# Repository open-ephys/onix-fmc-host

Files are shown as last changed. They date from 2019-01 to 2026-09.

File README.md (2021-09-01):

# ONIX FMC Host
This card provides a host interface for serialized headstages and miniscopes, as
well as general purpose analog and digital IO. It is a VITA-57.1
compliant module that uses high pin-count FMC connector. In combination with a
base FPGA board (e.g. [Numato Lab
Nereid](https://numato.com/product/nereid-kintex-7-pci-express-fpga-development-board),
it provides host PC communication for the following:

- Two deserailizers for any multifunction headstage conforming to the ONIX
  serialization protocol
- 12x 16-bit, +/-10V analog outputs or inputs. Direction selected via analog
  switch controllable over the FMC connector. Analog inputs are separated into
  2 simultaneously sampled 6-channel banks. 
- Analog output are always looped back using the analog inputs.
- 3x high speed LVDS input pairs
- 2x high speed LVDS outputs pairs
- 2x high speed, arbitrary logic-level, singled-ended Hi-Z or 50-ohm clock inputs
- 1x high speed single ended, 50-ohm clock output
- 4x MLVDS input or output trigger lines

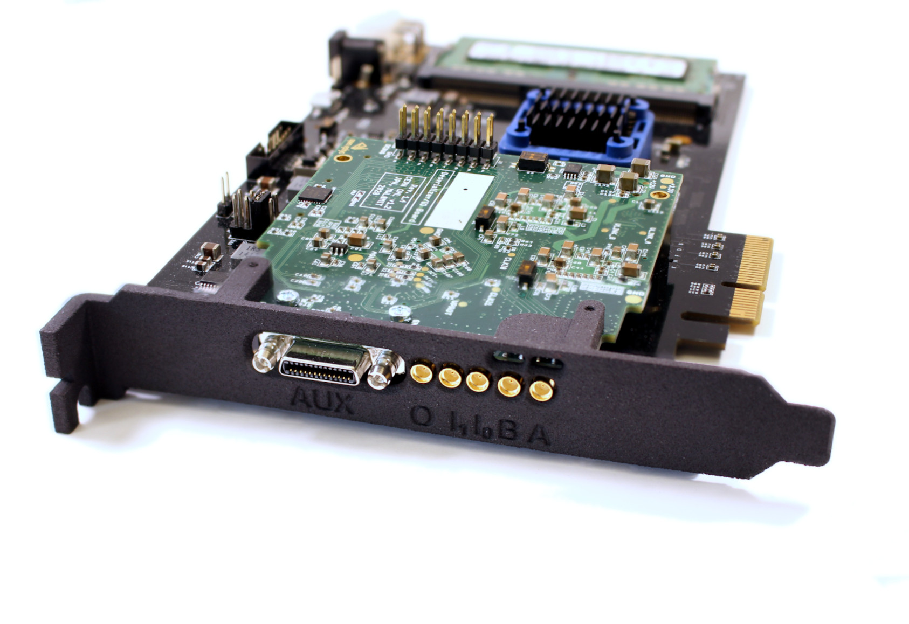
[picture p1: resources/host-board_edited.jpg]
fmc-host revision 1.4 on Numato Lab Nereid


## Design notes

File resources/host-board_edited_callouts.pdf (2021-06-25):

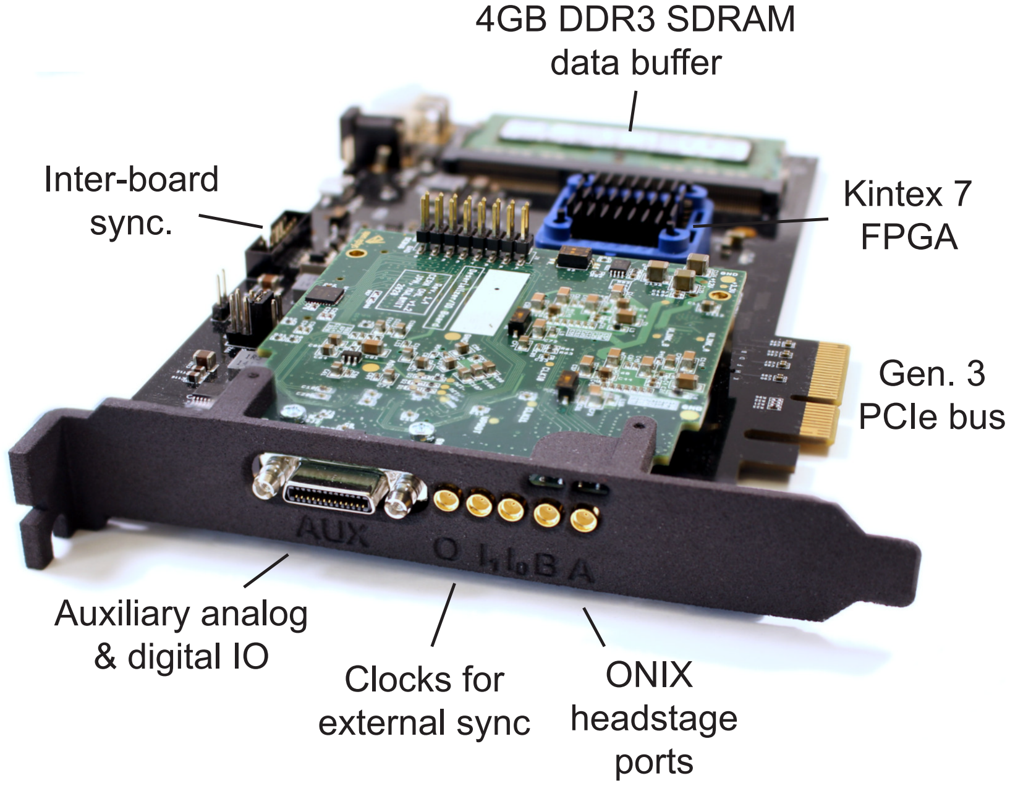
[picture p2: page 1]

Auxiliary analog
& digital IO | Clocks for
| external sync

ONIX
headstage
ports

Gen. 3
PCIe bus

4GB DDR3 SDRAM
data buffer

Kintex 7
FPGA

Inter-board
sync.

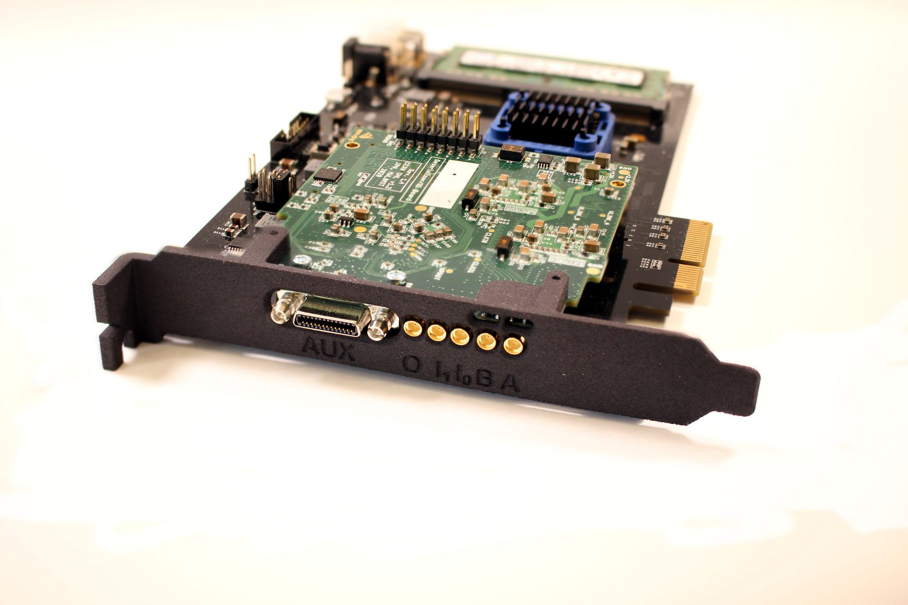
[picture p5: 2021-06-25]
resources/host-board-focus-stack.png

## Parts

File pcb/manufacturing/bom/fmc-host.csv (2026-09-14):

# | Qty | Reference | Value | Tolerance | Footprint | TempCo | Voltage | DNP | OEPS PN | MPN | LCSC | OEPS Description
1 | 23 | C1,C2,C5,C6,C26,C27,C34,C35,C36,C37,C70,C71,C72,C73,C79,C80,C81,C91,C92,C106,C118,C139,C140 | 10uF |  | fmc-host:1206 |  |  |  | OEPS010007 | GRM31CR71E106KA12L |  | CAPACITOR: SMD CER 1206 10uF 25V ±10% X7R [GRM31CR71E106KA12L] [SMD]
2 | 62 | C3,C4,C7,C8,C9,C10,C13,C14,C15,C16,C17,C18,C19,C22,C23,C30,C31,C32,C33,C41,C43,C44,C45,C46,C47,C48,C49,C52,C53,C54,C55,C56,C60,C61,C63,C65,C67,C68,C78,C83,C84,C85,C86,C87,C89,C90,C93,C99,C100,C104,C107,C110,C111,C112,C114,C132,C134,C135,C137,C138,C141,C142 | 0.1uF |  | fmc-host:0402 | X7R | 25V |  | OEPS010004 | GRM155R71E104KE14D |  | CAPACITOR: SMD CER 0402 100nF 25V ±10% X7R [GRM155R71E104KE14D] [SMD]
3 | 14 | C11,C12,C20,C21,C24,C25,C50,C51,C57,C58,C82,C122,C123,C124 | 10nF |  | fmc-host:0402 |  |  |  | OEPS010002 | GCM155R71E103KA37D |  | CAPACITOR: SMD CER 0402 10nF 25V ±10% X7R [GCM155R71E103KA37D] [SMD]
4 | 2 | C28,C29 | 4.7nF |  | fmc-host:0402 |  |  |  | OEPS010001 | CC0402KRX7R8BB472 |  | CAPACITOR: SMD CER 0402 4.7nF 25V ±10% X7R [CC0402KRX7R8BB472] [SMD]
5 | 2 | C38,C39 | 47nF |  | fmc-host:0402 |  |  |  | OEPS010003 | GRM155R71E473KA88D |  | CAPACITOR: SMD CER 0402 47nF 25V ±10% X7R [GRM155R71E473KA88D] [SMD]
6 | 8 | C40,C42,C64,C66,C74,C75,C76,C88 | 1uF |  | fmc-host:0805 |  |  |  | OEPS010005 | GCM21BR71E105KA56L |  | CAPACITOR: SMD CER 0805 1uF 25V ±10% X7R [GCM21BR71E105KA56L] [SMD]
7 | 20 | C59,C62,C69,C77,C95,C96,C101,C103,C105,C108,C109,C113,C116,C117,C119,C120,C121,C125,C126,C127 | 10uF |  | fmc-host:0805 |  |  |  | OEPS010006 | GRM21BR61E106KA73L |  | CAPACITOR: SMD CER 0805 10uF 25V ±10% X5R [GRM21BR61E106KA73L] [SMD]
8 | 6 | C94,C97,C98,C102,C130,C131 | 47uF |  | fmc-host:1210 |  |  |  | OEPS010008 | TMK325ABJ476MM-T |  | CAPACITOR: SMD CER 1210 47uF 25V ±20% X5R [TMK325ABJ476MM-T] [SMD]
9 | 1 | C115 | 100pF |  | fmc-host:0402 |  |  |  | OEPS010089 | CC0402JRNPO9BN101 |  | CAPACITOR: SMD CER 0402 100pF 50V ±5% C0G [CC0402JRNPO9BN101] [SMD]
10 | 2 | C128,C129 | 0.1uF, 500V |  | fmc-host:1210 |  |  |  | OEPS010091 | C1210C104KCRACTU |  | CAPACITOR: SMD CER 1210 100nF 500V ±10% X7R [C1210C104KCRACTU] [SMD]
11 | 2 | C133,C136 | 33uF |  | fmc-host:1411-VISHAY-B |  |  |  | OEPS210010 | TL8B0336M020C |  | CAPACITOR POL: SMD TANT B0 1411 33uF 20V ±20% 50Ohm [TL8B0336M020C] [SMD]
12 | 2 | D1,D2 | SESD0402X1UN-0030-088 |  | fmc-host:0402P-DFN |  |  |  | OEPS030049 | SESD0402X1UN-0030-088 |  | DIODE: TVS DIODE 7VWM 13VC [SESD0402X1UN-0030-088] [0402/2DFN]
13 | 3 | D3,D4,D5 | BAR66 |  | fmc-host:SOT23 |  |  |  | OEPS030050 | BAR66E6327HTSA1 |  | DIODE: RF DIODE PIN 150V 250MW [BAR66E6327HTSA1] [PG-SOT23]
14 | 1 | D6 | KDZVTR4.3B |  | fmc-host:SOD123 |  |  |  | OEPS030051 | KDZVTR4.3B |  | DIODE: DIODE ZENER 4.55V 1W [KDZVTR4.3B] [PMDU]
15 | 3 | F1,F2,F3 | C014F-2 |  | fmc-host:1812 |  |  |  | OEPS100088 | MINISMDC014F-2 |  | OTHER: PTC RESET FUSE 60V 140MA 1812 [MINISMDC014F-2] [Other]
16 | 5 | J1,J2,J3,J4,J5 | 6-1634010-0 |  | fmc-host:MMCX-THRU |  |  |  | OEPS070081 | 262105 |  | CONNECTOR: MMCX RCPT 50ohm 90º [262105] [TH]
17 | 1 | J6 | FTSH-105-01-F-D-RA-K |  | fmc-host:FTSH-105-01-F-D-RA-K |  |  |  | OEPS070147 | FTSH-105-01-F-D-RA-K |  | CONNECTOR: HEADER 1.27MM R/A 10POS [FTSH-105-01-F-D-RA-K] [TH]
18 | 1 | J7 | 12226-8250-00FR |  | fmc-host:12226-82X0-00XX |  |  |  | OEPS070009 | 12226-8250-00FR |  | CONNECTOR: SDR RCPT 90º 26POS [12226-8250-00FR] [SMD]
19 | 1 | J9 | ASP-134488-01 |  | fmc-host:FMC_HPC_MALE |  |  |  | OEPS070148 | ASP-134488-01 |  | CONNECTOR: ARRAY PLUG 400POS GOLD [ASP-134488-01] [SMD]
20 | 1 | J10 | BM08B-SURS-TF |  | fmc-host:BM08B-SURS-TF |  |  |  | OEPS070149 | BM08B-SURS-TF |  | CONNECTOR: HEADER 0.8MM 8POS [BM08B-SURS-TF] [SMD]
21 | 2 | L1,L2 | 1008PS-472 |  | fmc-host:1008PS |  |  |  | OEPS040032 | 1008PS-472KLC |  | INDUCTOR: FIXED INDUCTOR SMD 4.7uH 950mA 350mΩ [1008PS-472KLC] [-]
22 | 6 | L3,L4,L9,L10,L11,L12 | BLM18KG601SN1D |  | fmc-host:0603 |  |  |  | OEPS040029 | BLM18KG601SN1D |  | INDUCTOR: FERRITE BEAD SMD 0603 600Ω 1.3A 150mΩ (OEPS J30 030) [BLM18KG601SN1D] [0603]
23 | 2 | L5,L6 | SRN6045TA-101M |  | fmc-host:SRN6045TA |  |  |  | OEPS040033 | SRN6045TA-101M |  | INDUCTOR: FIXED INDUCTOR SMD 100uH 920mA 456mΩ [SRN6045TA-101M] [SMD]
24 | 2 | L7,L8 | MPZ2012S102AT000 |  | fmc-host:0805 |  |  |  | OEPS040034 | MPZ2012S102AT000 |  | INDUCTOR: FERRITE BEAD SMD 0805 1kΩ 1.5A 150mΩ [MPZ2012S102AT000] [SMD]
25 | 1 | L13 | 1277AS-H-6R8M=P2 |  | fmc-host:1210 |  |  |  | OEPS040035 | 1277AS-H-6R8M=P2 |  | INDUCTOR: FIXED INDUCTOR SMD 6.8uH 1.2A 276mΩ [1277AS-H-6R8M=P2] [SMD]
26 | 6 | L14,L15,L16,L17,L18,L19 | BLM15PX601SN1D |  | fmc-host:0402 |  |  |  | OEPS040019 | BLM15PX601SN1D |  | INDUCTOR: FERRITE BEAD SMD 0402 600Ω 900mA 230mΩ [BLM15PX601SN1D] [0402]
27 | 4 | Q1,Q2,Q3,Q4 | SI1012R |  | fmc-host:SC75 |  |  |  | OEPS060024 | SI1012CR-T1-GE3 |  | TRANSISTOR: MOSFET N-CH 20V 630mA [SI1012CR-T1-GE3] [SC-75A]
28 | 4 | R1,R2,R38,R39 | 3k |  | fmc-host:0402 |  |  |  | OEPS020008 | ERJ-2RKF3001X |  | RESISTOR: SMD 0402 3kΩ ±1% 0.100W [ERJ-2RKF3001X] [SMD]
29 | 6 | R3,R4,R9,R10,R57,R58 | 2k |  | fmc-host:0402 |  |  |  | OEPS020007 | ERJ-2RKF2001X |  | RESISTOR: SMD 0402 2kΩ ±1% 0.100W [ERJ-2RKF2001X] [SMD]
30 | 6 | R5,R6,R7,R8,R11,R12 | 150,0.25W |  | fmc-host:0603 |  |  |  | OEPS020023 | CRGP0603F150R |  | RESISTOR: SMD 0603 150Ω ±1% 0.250W [CRGP0603F150R] [SMD]
31 | 9 | R13,R14,R49,R50,R51,R52,R76,R83,R84 | 165k |  | fmc-host:0402 |  |  |  | OEPS020020 | ERJ-2RKF1653X |  | RESISTOR: SMD 0402 165kΩ ±1% 0.100W [ERJ-2RKF1653X] [SMD]
32 | 13 | R15,R16,R35,R37,R59,R63,R64,R65,R67,R68,R78,R79,R82 | 10k |  | fmc-host:0402 |  |  |  | OEPS020013 | ERJ-2RKF1002X |  | RESISTOR: SMD 0402 10kΩ ±1% 0.100W [ERJ-2RKF1002X] [SMD]
33 | 8 | R17,R18,R41,R42,R44,R45,R46,R47 | 1k |  | fmc-host:0402 |  |  |  | OEPS020006 | ERJ-2RKF1001X |  | RESISTOR: SMD 0402 1kΩ ±1% 0.100W [ERJ-2RKF1001X] [SMD]
34 | 2 | R19,R21 | 5.6k 1% |  | fmc-host:0402 |  |  |  | OEPS020011 | ERJ-2RKF5601X |  | RESISTOR: SMD 0402 5.6kΩ ±1% 0.100W [ERJ-2RKF5601X] [SMD]
35 | 2 | R20,R22 | 21k 1% |  | fmc-host:0402 |  |  |  | OEPS020016 | ERJ-2RKF2102X |  | RESISTOR: SMD 0402 21kΩ ±1% 0.100W [ERJ-2RKF2102X] [SMD]
36 | 4 | R23,R24,R28,R29 | 49.9 |  | fmc-host:0402 |  |  |  | OEPS020002 | RR0510R-49R9-D |  | RESISTOR: SMD 0402 49.9Ω ±0.5% 0.063W [RR0510R-49R9-D] [SMD]
37 | 3 | R25,R26,R27 | 100 |  | fmc-host:0402 |  |  |  | OEPS020004 | ERJ-2RKF1000X |  | RESISTOR: SMD 0402 100Ω ±1% 0.100W [ERJ-2RKF1000X] [SMD]
38 | 9 | R30,R31,R32,R33,R40,R43,R71,R73,R75 | 4.7k |  | fmc-host:0402 |  |  |  | OEPS020010 | ERJ-2RKF4701X |  | RESISTOR: SMD 0402 4.7kΩ ±1% 0.100W [ERJ-2RKF4701X] [SMD]
39 | 2 | R34,R36 | DNP |  | fmc-host:0402 |  |  | DNP | OEPS000000 | DNP |  | DNP: Do Not Populate (DNI)
40 | 2 | R48,R66 | 0 |  | fmc-host:0402 |  |  |  | OEPS020001 | RC0402JR-070RL |  | RESISTOR: SMD 0402 0Ω 1A [RC0402JR-070RL] [SMD]
41 | 4 | R53,R54,R55,R56 | 2.2k |  | fmc-host:RN2X8-1506 |  |  |  | OEPS080206 | EXB-2HV222JV |  | IC: RES ARRAY 8 RES 2.2K OHM 1506 [EXB-2HV222JV] [SMD]
42 | 2 | R60,R61 | 3.48k |  | fmc-host:0402 |  |  |  | OEPS020009 | ERJ-2RKF3481X |  | RESISTOR: SMD 0402 3.48kΩ ±1% 0.100W [ERJ-2RKF3481X] [SMD]
43 | 1 | R62 | 649k |  | fmc-host:0402 |  |  |  | OEPS020022 | ERJ-2RKF6493X |  | RESISTOR: SMD 0402 649kΩ ±1% 0.100W [ERJ-2RKF6493X] [SMD]
44 | 1 | R69 | 2.2k |  | fmc-host:0402 |  |  |  | OEPS020174 | ERJ-2RKF2201X |  | RESISTOR: SMD 0402 2.2kΩ ±1% 0.100W [ERJ-2RKF2201X] [SMD]
45 | 1 | R70 | 15k |  | fmc-host:0402 |  |  |  | OEPS020015 | ERJ-2RKF1502X |  | RESISTOR: SMD 0402 15kΩ ±1% 0.100W [ERJ-2RKF1502X] [SMD]
46 | 2 | R72,R74 | 47k |  | fmc-host:0402 |  |  |  | OEPS020017 | ERJ-2RKF4702X |  | RESISTOR: SMD 0402 47kΩ ±1% 0.100W [ERJ-2RKF4702X] [SMD]
47 | 1 | R77 | 178k |  | fmc-host:0402 |  |  |  | OEPS020021 | ERJ-2RKF1783X |  | RESISTOR: SMD 0402 178kΩ ±1% 0.100W [ERJ-2RKF1783X] [SMD]
48 | 2 | R80,R81 | 73.2k |  | fmc-host:0402 |  |  |  | OEPS020018 | ERJ-2RKF7322X |  | RESISTOR: SMD 0402 73.2kΩ ±1% 0.100W [ERJ-2RKF7322X] [SMD]
49 | 2 | R289,R290 | 4.7,1W |  | Resistor_SMD:R_1206_3216Metric |  |  |  | OEPS020260 | SG73P2BTTD4R7J |  | RESISTOR: SMD 1206 4.7Ω ±5% 1W [SG73P2BTTD4R7J] [SMD]
50 | 2 | S1,S2 | CHS-01TA |  | fmc-host:DIP01-SMD-GULL |  |  | DNP | OEPS100086 | CHS-01TA |  | OTHER: SWITCH SLIDE DIP SPST 0.1A 6V 1 POS [CHS-01TA] [Other]
51 | 1 | S3 | CHS-02TB |  | fmc-host:CHS-02TB |  |  |  | OEPS100087 | CHS-02TB |  | OTHER: SWITCH SLIDE DIP SPST 0.1A 6V 2 POS [CHS-02TB] [Other]
52 | 1 | U1 | SN74LVC2G34DCKR |  | fmc-host:SC70 |  |  |  | OEPS080207 | SN74LVC2G34DCKR |  | IC: BUFFER NON-INVERT 2CH [SN74LVC2G34DCKR] [SC-70-6]
53 | 1 | U2 | SN65LVDS9638DGN |  | fmc-host:MSOP-8-PAD-3X3 |  |  |  | OEPS080007 | SN65LVDS9638DGN |  | IC: LVDS 2channel driver [SN65LVDS9638DGN] [8-MSOP-PowerPad]
54 | 1 | U3 | FIN1032MTCX |  | fmc-host:TSSOP-16 |  |  |  | OEPS080006 | FIN1032MTCX |  | IC: LVDS 4channel receiver [FIN1032MTCX] [16-TSSOP]
55 | 2 | U4,U5 | ADCMP600 |  | fmc-host:SOT-23-5 |  |  |  | OEPS080208 | ADCMP600BRJZ-R2 |  | IC: COMPARATOR 1 GP [ADCMP600BRJZ-R2] [SOT23-5]
56 | 3 | U6,U7,U8 | DG1412E |  | fmc-host:QFN16-4X4MM |  |  |  | OEPS080209 | DG1412EEN-T1-GE4 |  | IC: SWITCH SPST-NOX4 1.5OHM [DG1412EEN-T1-GE4] [16-QFN (4x4)]
57 | 2 | U9,U10 | DS90UB934-Q1 |  | fmc-host:WQFN48-7X7-PAD |  |  |  | OEPS080210 | DS90UB934TRGZRQ1 |  | IC: DESERIALIZER FPD-Link III [DS90UB934TRGZRQ1] [48-VQFN (7x7)]
58 | 1 | U11 | DS91M040 |  | fmc-host:WQFN32-5X5 |  |  |  | OEPS080211 | DS91M040TSQ/NOPB |  | IC: TRANSCEIVER Half LVDS [DS91M040TSQ/NOPB] [32-WQFN (5x5)]
59 | 1 | U12 | AD5766BCPZ-RL7 |  | fmc-host:CP_40_7 |  |  |  | OEPS080212 | AD5766BCPZ-RL7 |  | IC: DAC 16BIT 16CH [AD5766BCPZ-RL7] [40-LFCSP-WQ (6x6)]
60 | 1 | U13 | MCP47FEB02A0-E/ST |  | fmc-host:TSSOP-8 |  |  |  | OEPS080213 | MCP47FEB02A0-E/ST |  | IC: DAC 8BIT 2CH [MCP47FEB02A0-E/ST] [8-TSSOP]
61 | 1 | U14 | LM4132AMF-2.5/NOPB |  | fmc-host:SOT-23-5 |  |  |  | OEPS080214 | LM4132AMF-2.5/NOPB |  | IC: VREF 2.5V 0.05% [LM4132AMF-2.5/NOPB] [SOT-23-5]
62 | 1 | U15 | AD7616BSTZ |  | fmc-host:ST_80_2 |  |  |  | OEPS080205 | AD7616BSTZ |  | IC: ADC 16BIT 16 channels [AD7616BSTZ] [80-LQFP]
63 | 1 | U16 | AD5142BRUZ10 |  | fmc-host:TSSOP-16_4.4X5.0 |  |  |  | OEPS080118 | AD5142BRUZ10 |  | IC: DGT POT 10KOHM 256TAP 16TSSOP [AD5142BRUZ10] [16-TSSOP]
64 | 1 | U17 | LTM4622A |  | fmc-host:BGA_5X5_625X625 |  |  |  | OEPS080003 | LTM4622AIY#PBF |  | IC: DC-DC CONVERTER 2outputs1.5-12V 1.5-12V [LTM4622AIY#PBF] [25-BGA]
65 | 3 | U18,U25,U26 | D3V3XA4B10LP |  | Package_DFN_QFN:Diodes_UDFN-10_1.0x2.5mm_P0.5mm |  |  |  | OEPS080204 | D3V3XA4B10LP-7 |  | IC: TVS DIODE ARRAY [D3V3XA4B10LP-7] [10-UFDFN]
66 | 2 | U19,U20 | TPS7A49 |  | fmc-host:PVSON-N8+4-3X3 |  |  |  | OEPS080215 | TPS7A4901DRBR |  | IC: LDO ADJ 150mA [TPS7A4901DRBR] [8-SON (3x3)]
67 | 1 | U21 | TPS7A30 |  | fmc-host:PVSON-N8+4-3X3 |  |  |  | OEPS080216 | TPS7A3001DRBT |  | IC: LDO NEGATIVE ADJ 200mA [TPS7A3001DRBT] [8-SON (3x3)]
68 | 1 | U22 | 24AA64-I/ST |  | fmc-host:TSSOP8 |  |  |  | OEPS080217 | 24AA64-I/ST |  | IC: EEPROM 64KBIT I2C [24AA64-I/ST] [8-TSSOP]
69 | 1 | U23 | LTM8049IY#PBF |  | fmc-host:LTM8049 |  |  |  | OEPS080218 | LTM8049IY#PBF |  | IC: DC DC CONVERTER ADJ 2outputs 2x1A [LTM8049IY#PBF] [77-BGA (15x9)]
70 | 1 | U24 | TPS62061DSGT |  | fmc-host:WSON8-2X2 |  |  |  | OEPS080219 | TPS62061DSGT |  | IC: FIXED REG BUCK 1.8V 1.6A [TPS62061DSGT] [8-WSON (2x2)]
71 | 1 | U27 | TLV9062IDSGR |  | Package_SON:WSON-8-1EP_2x2mm_P0.5mm_EP0.9x1.6mm |  |  |  | OEPS080246 | TLV9062IDSGR |  | IC: OPAMP 2 CIRCUIT [TLV9062IDSGR] [8-WSON]
72 | 1 | U28 | SN74LVC2G14DBV |  | Package_TO_SOT_SMD:SOT-23-6 |  |  |  | OEPS080247 | SN74LVC2G14DBVR |  | IC: BUFFER INVERT 2CH SCHMITT-TRIGGER [SN74LVC2G14DBVR] [SOT-23-6]

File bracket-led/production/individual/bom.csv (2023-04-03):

Designator | Footprint | Quantity | Value | LCSC Part #
D1, D2 | EVERLIGHT_6-SMD-1.6x1.6 | 2 | LED_RGB | C131204
H1, H2 | BIVAR_SLP3-150-100-R | 2 | SLP3-150-100-R
J1 | JST_SM08B-SURS-TF(LF)(SN) | 1 | SM08B-SURS-TF(LF)(SN) | C595161

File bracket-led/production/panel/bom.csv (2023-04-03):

Designator | Footprint | Quantity | Value | LCSC Part #
D1_15, D1_14, D1_13, D1_12, D1_11, D1_10, D1_9, D1_8, D1_7, D1_6, D1_5, D1_4, D1_3, D1_2, D1, D2_15, D2_14, D2_13, D2_12, D2_11, D2_10, D2_9, D2_8, D2_7, D2_6, D2_5, D2_4, D2_3, D2_2, D2 | EVERLIGHT_6-SMD-1.6x1.6 | 30 | LED_RGB | C131204
H1_15, H1_14, H1_13, H1_12, H1_11, H1_10, H1_9, H1_8, H1_7, H1_6, H1_5, H1_4, H1_3, H1_2, H1, H2_15, H2_14, H2_13, H2_12, H2_11, H2_10, H2_9, H2_8, H2_7, H2_6, H2_5, H2_4, H2_3, H2_2, H2 | BIVAR_SLP3-150-100-R | 30 | SLP3-150-100-R
J1_15, J1_14, J1_13, J1_12, J1_11, J1_10, J1_9, J1_8, J1_7, J1_6, J1_5, J1_4, J1_3, J1_2, J1 | JST_SM08B-SURS-TF(LF)(SN) | 15 | SM08B-SURS-TF(LF)(SN) | C595161

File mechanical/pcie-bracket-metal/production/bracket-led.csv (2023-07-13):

Id | Designator | Footprint | Quantity | Designation | Supplier and ref
1 | D2,D1 | EVERLIGHT_6-SMD-1.6x1.6 | 2 | LED_RGB
2 | H1,H2 | BIVAR_SLP3-150-100-R | 2 | SLP3-150-100-R
3 | J1 | JST_SM08B-SURS-TF(LF)(SN) | 1 | SM08B-SURS-TF(LF)(SN)
4 |  |  | 1 | A08SUR08SUR32W102B

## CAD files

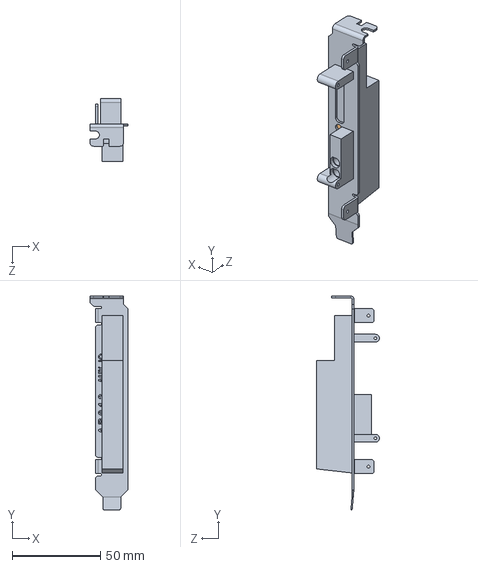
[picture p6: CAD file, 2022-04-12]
mechanical/pcie-bracket-3dprint/pcie-bracket.SLDASM
21.6 x 121.0 x 35.5 mm
pcie-bracket-1p27mm
mmcx-gang

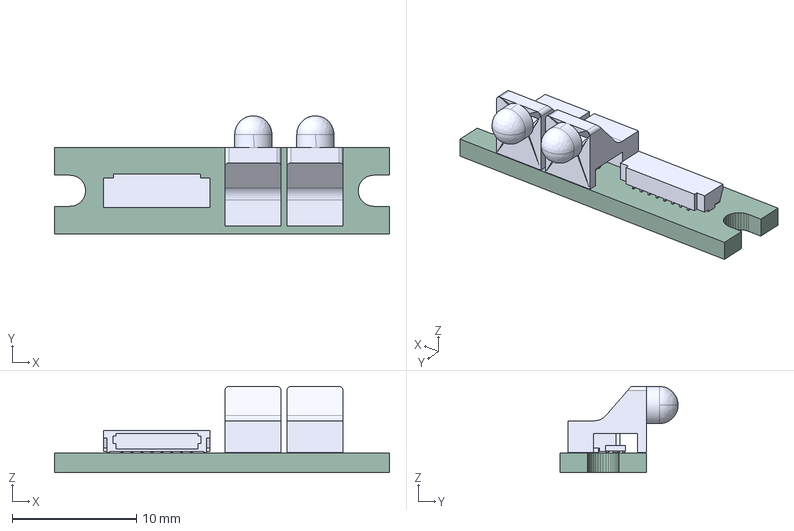
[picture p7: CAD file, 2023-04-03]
bracket-led/source/bracket-led.step
27.0 x 9.54 x 6.94 mm
PCB

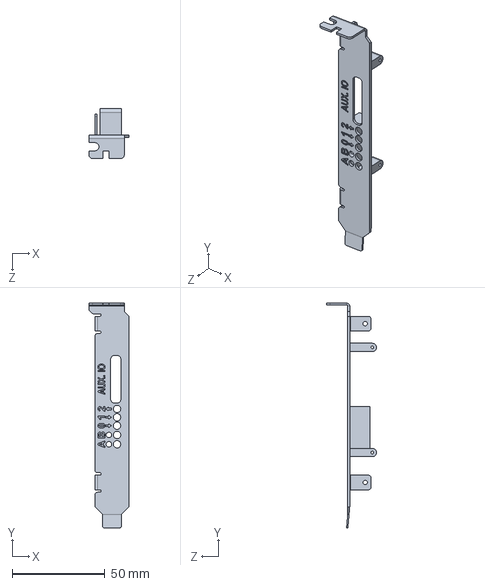
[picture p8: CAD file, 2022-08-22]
mechanical/pcie-bracket-3dprint/pcie-bracket-1p27mm.SLDPRT
21.6 x 121.0 x 27.0 mm

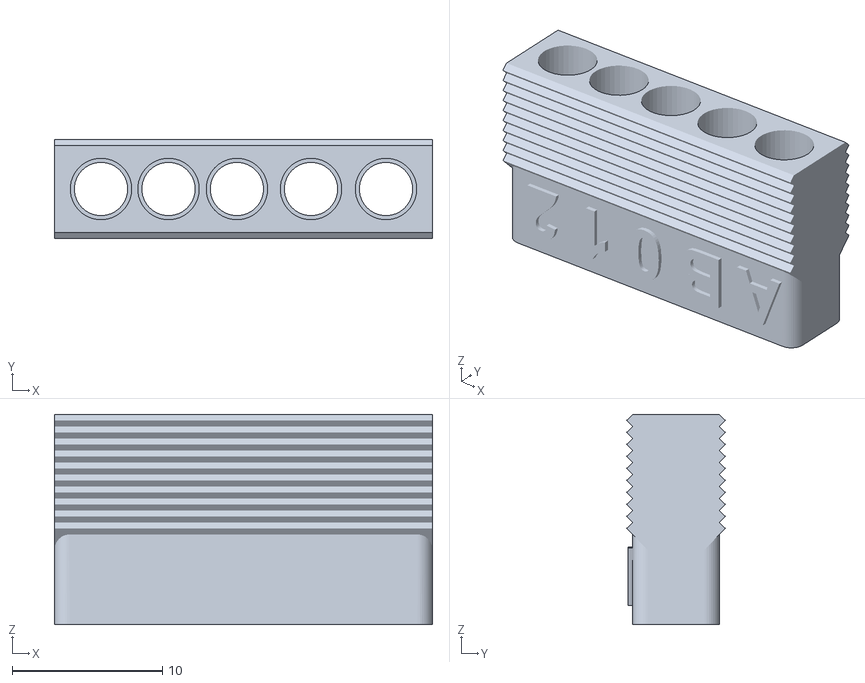
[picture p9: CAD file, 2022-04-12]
mechanical/pcie-bracket-3dprint/stl/mmcx-gang-host.STL
25.2 x 6.58 x 14.0

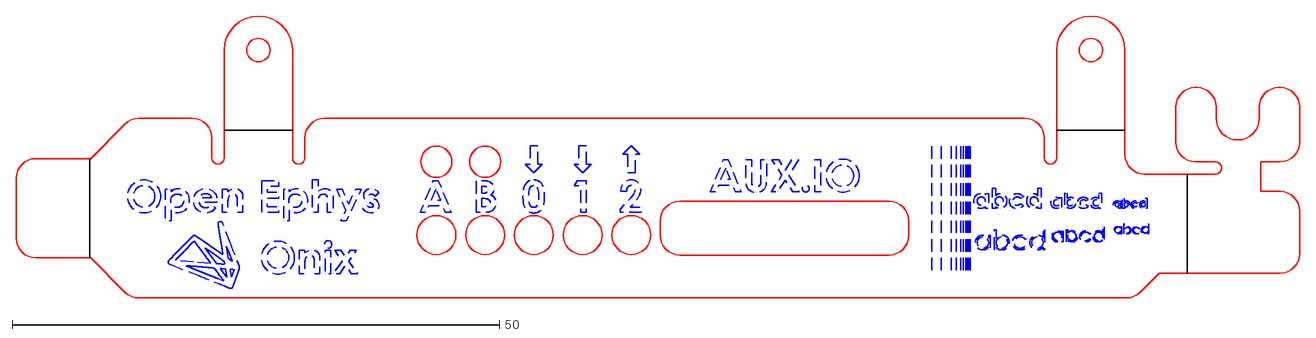
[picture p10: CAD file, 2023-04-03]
mechanical/pcie-bracket-metal/mechanical/production/Flat pattern - pcie bracket glue.DXF
131.6 x 28.9

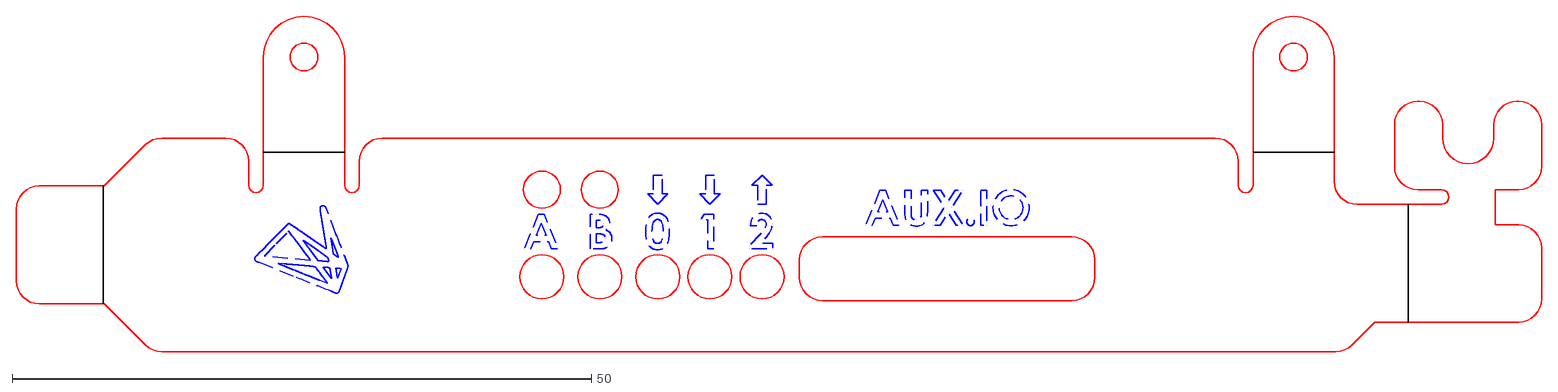
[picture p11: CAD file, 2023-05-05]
mechanical/pcie-bracket-metal/production/flat-pattern_pcie-bracket-glue.DXF
131.6 x 28.9

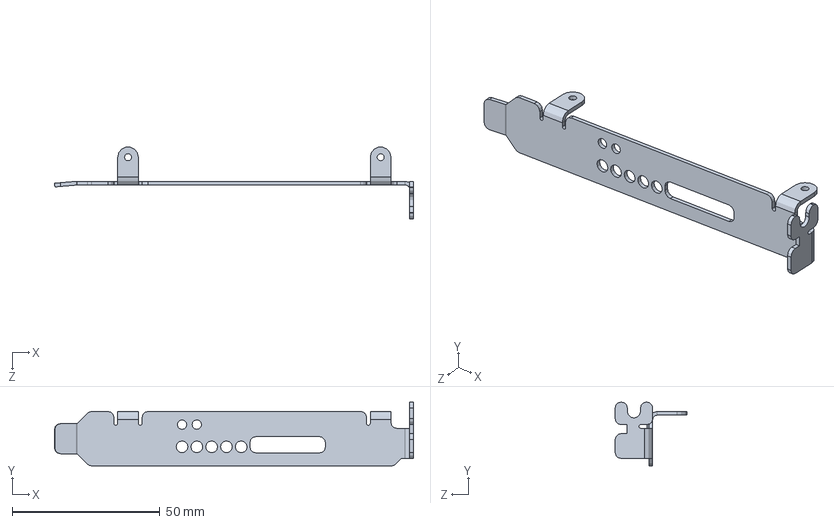
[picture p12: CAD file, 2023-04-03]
mechanical/pcie-bracket-metal/mechanical/pcie bracket glue.SLDPRT
121.4 x 21.6 x 24.2 mm

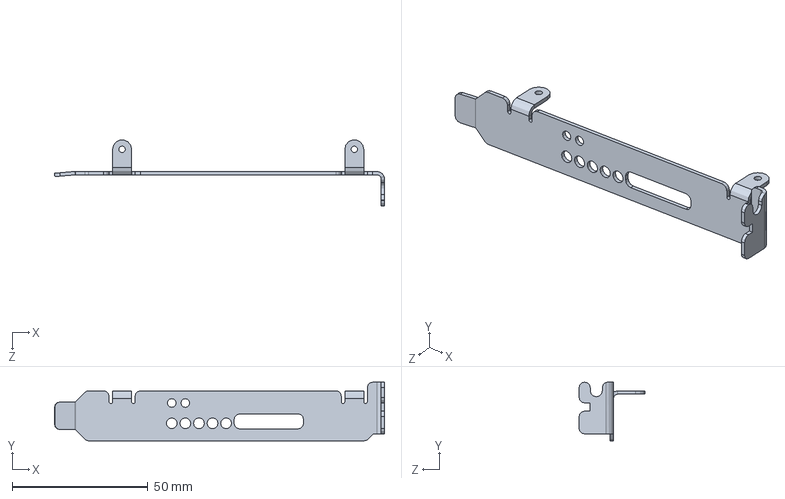
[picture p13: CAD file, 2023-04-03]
mechanical/pcie-bracket-metal/mechanical/production/pcie bracket glue questionable flange support.SLDPRT
121.4 x 21.6 x 24.2 mm

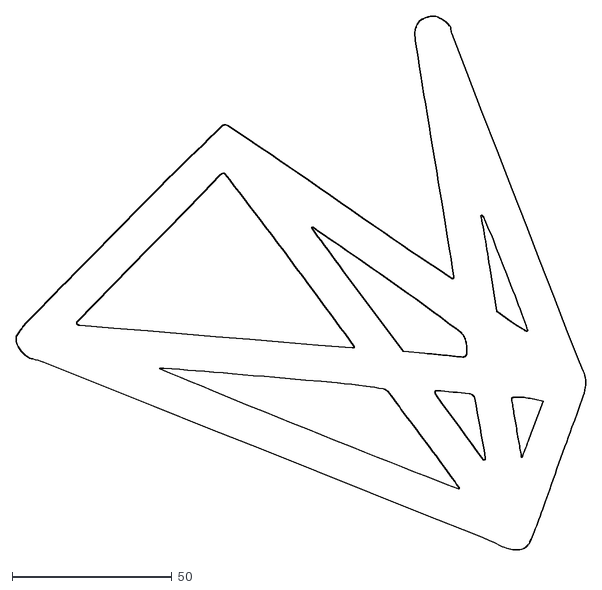
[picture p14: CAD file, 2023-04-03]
mechanical/pcie-bracket-metal/source/oe_logo_circle.dxf
178.2 x 166.9

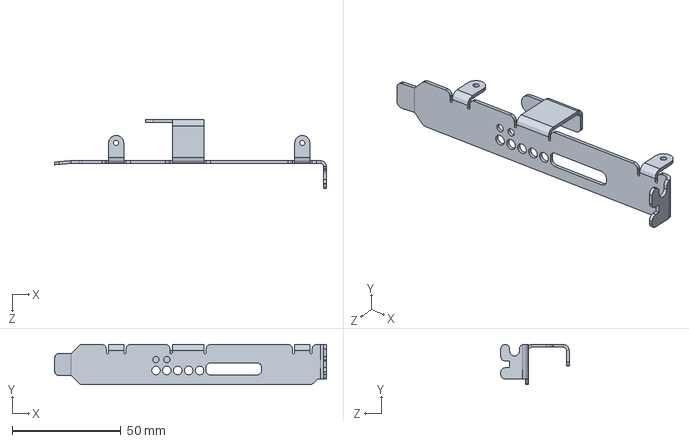
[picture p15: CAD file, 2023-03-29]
mechanical/pcie-bracket-metal/source/pcie-bracket-overhang.SLDPRT
124.8 x 18.4 x 31.5 mm

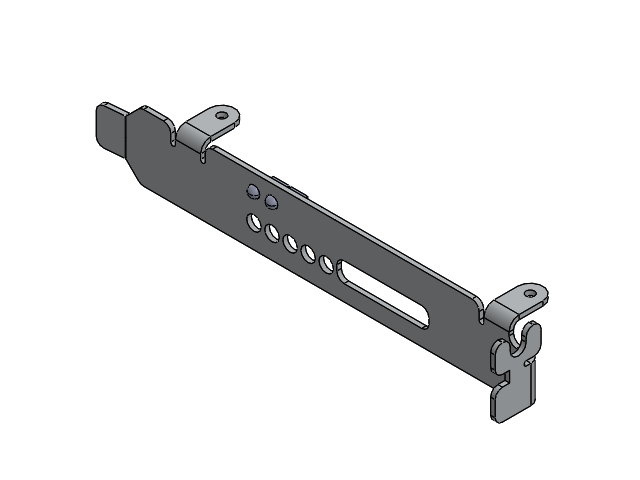
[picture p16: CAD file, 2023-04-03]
mechanical/pcie-bracket-metal/mechanical/pcie bracket glue assembly.SLDASM
COMPOUND_8.step x 2
SOLID_8.step
SOLID-0_8.step x 2
PCB_8.step
pcie bracket glue

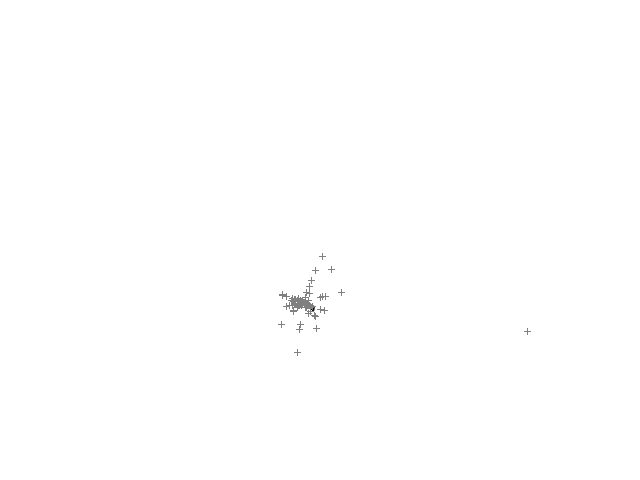
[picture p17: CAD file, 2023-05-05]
mechanical/pcie-bracket-metal/source/pcie-bracket-glue-assembly.SLDASM
COMPOUND_8.step x 2
SOLID_8.step
SOLID-0_8.step x 2
PCB_8.step
pcie-bracket-glue

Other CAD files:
mechanical/pcie-bracket-metal/source/pcie-bracket-glue.SLDPRT
mechanical/pcie-bracket-3dprint/mmcx-gang.SLDPRT
mechanical/pcie-bracket-metal/mechanical/bracket-led.step
mechanical/pcie-bracket-metal/source/bracket-led.step
mechanical/pcie-bracket-metal/mechanical/pcie bracket glue questionable flange support.SLDPRT
mechanical/pcie-bracket-3dprint/stl/pcie-bracket-1p27mm.STL
mechanical/pcie-bracket-metal/mechanical/bracket-led.SLDASM
mechanical/pcie-bracket-metal/source/bracket-led.SLDASM

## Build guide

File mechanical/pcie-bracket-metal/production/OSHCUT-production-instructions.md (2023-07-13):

# Ordering and Assembling the PCIe Brackets With LED Indicators

## Ordering

### Sheet Metal Bracket

#### If You Are Ordering This Part from Osh Cut for the First Time:

1) Visit https://app.oshcut.com/cart
2) Sign up or sign in to Osh Cut if you want to reorder these parts in the future
3) Click *Upload* and select *flat-pattern_pcie-bracket-glue.DXF* located in this directory
4) Click *Select Units* and select *mm*
5) Click *Select Material* and select *0.05" 5052 H32 Aluminum, Formable*
6) Click *Resolve* by the *Design Check* label and select bend lines 1-by-1 going clockwise starting at 9 o'clock the 
   and assign the following bend properties:
   1) Bend (9 o'clock): 175° Up
   2) Bend (11:30): 90° Down
   3) Bend (12:30): 90° Down
   4) Bend (3 o'clock): 90° Up
7) Click the *3D View* button to confirm the bends/engravings are properly assigned and the visualization reflects the 
   physical part you want
8) Go back to cart and select part quantity
9) Click the *Proceed to Checkout* button to proceed to checkout

#### If You've Previously Ordered This Part With an Osh Cut Account and Are Reordering Parts Without Modification:

1) Visit https://app.oshcut.com/cart
2) Sign in to Osh Cut and click the *Order History* tab
3) Click *Add all to order* and click the *Current Order* tab to return
4) Select part quantity
5) Click the *Proceed to Checkout* button to proceed to checkout

### LED PCB:

1) Visit the website of the PCB manufacturer you intend to use to manufacture this part (using knowledge about 
   production quanity, part complexity, and manufacturer capabilities)
2) Sign in if you have an account if you plan on reordering this partnow or in the future
3) Upload the Gerber zip file located in this directory
4) Select part quantity and appropriate manufacturing options
5) Proceed to checkout

## Assembly

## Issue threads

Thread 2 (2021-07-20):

PCIe bracket requires redesign

jonnew, 2021-07-20:
- RGB LEDs are not really visible on most computers
- Users report that that part that the screw fits into is too thick for most computers
- The labels are very difficult to read

ablot, 2021-07-20:
I had a very hard time to fit it into my computer case. As Jon mentioned, the short part where the screw go is too thick, but mine was also a bit too tall. There was a gap between the bracket and the case. It's easier to draw:

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

The labels were not an issue (easy enough to read).

jvoigts, 2021-07-21:
Yea this is a somewhat known issue. We'll try if we can make the plastic a bit thinner (both at the bottom and the top) without making the part too weak. The 'real' solution would be to get a proper sheet metal one made, we'll look into this for the post-beta versions. The LEDs should be easy to fix by making the openings bigger, and the text could be done for example by filling the debossed text with paint, though that would add a manual step. Maybe the label upgrade can wait till we do sheet metal?

jonnew, 2021-07-22:
I think the best solution for the LEDs and labeling could potentially be a sticker: labeling fix is obvious and then the sticker could go over the LED openings and act as a diffusor? Maybe dumb I dunno.

jonnew, 2021-07-23:
Or even somehow make the openings for the LEDs optically continuous with the space around the MMCX connectors so there is a right of light around the connector when its plugged in. That would be nice.

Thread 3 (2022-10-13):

Low-level hardware failure in specific computer(s)

jvoigts, 2022-10-13:
In one specific computer, there seems to be a low-level hardware failure that can be replicated in the C program.
The computer is a pretty beefy puget systems machine, shouldn't have any intrinsic issues with power etc. The machine is also spec'd for 2 big GPUs and I replicated the issue with one GPU removed.

Steps taken to replicate:
- Use FMC host in specific PC, no external hardware needs to be connected.
- Turn on a analog io stream in bonsai (or in console app?) (could be anything but this seems to work to generate some load)
- Run the liboni-test program, set print frequency to 100.000 ( 'D' '100000'), then turn on logging ('d')
- Wait for updates to stop 😢
- If using a firmware that outputs memory usage on the FMC, read dev_idx 10, reg_addr 4, to see if memory usage keeps going up ('r' '10 4'), In my case the value keeps going up.

In another, much lower spec, PC the same FMC with the same drivers etc. ran for 2 days without issues 🤷.

Next steps: try another FMC board in the puget systems PC to see if it's a specific interaction of that FMC and that PC.

Hypotheses so far: power instability on PCIe? This would likely be a numato related issue?

jonnew, 2024-10-31:
I think this was because the PXI power supply was not plugged into the PCIe board, causing power instability. Closing for now. Feel free to re-open if issue is still a concern.

Closed 2024-10-31.

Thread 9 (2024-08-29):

U3 can be damaged by plugging in breakout board when power is on

jonnew, 2024-08-29:
The PCIe controller with onix-fmc-host attached is inside a computer and powered on when the breakout board is plugged via the shrunk-delta ribbon cable, U3 can become degraded and eventually fail catastrophically. This never occurs if the breakout board is plugged when power is off.

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

- Is there some way to keep this chip disabled until the breakout is detected?
- Would this even help? Given that this is a reciever, we need top probe the input lines during a hot plug in event to see what they are doing.

filcarv, 2024-09-16:
Could you check if these PN and cases are the right ones?

SN65LVDS33PWR 400 MBps
SN65LVDS32PWR 100 Mbps
DS90LV032ATMTCX/NOPB 400 Mbps

jonnew, 2024-09-16:
Yes, here is my verification:

Original part: FIN1032MTCX
- TSSOP-16 4.4x5mm with 0.65mm pitch
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

Replacements:
1. SN65LVDS33PWR
    - TSSOP-16 4.4x5mm with 0.65mm pitch
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

2. SN65LVDS32PWR (datasheet says 150  Mbps, not 100)
    -  TSSOP-16 4.4x5mm with 0.65mm pitch
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

3. DS90LV032ATMTCX/NOPB
    - TSSOP-16 4.4x5mm with 0.65mm pitch
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

jonnew, 2024-10-13:
In addition to this, I also ordered some TVS diodes:

- [RCLAMP0582B.TCTCT-ND](https://www.digikey.com/en/products/detail/semtech-corporation/RCLAMP0582B-TCT/4626644)
- [RCLAMP3552TQTNTCT-ND](https://www.digikey.com/en/products/detail/semtech-corporation/RCLAMP3552TQTNT/9384933)

To try to hack into the U3's LVDS RX ports:

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

I want to know if this solves the issue and is a bodge we can make on the fmc units.

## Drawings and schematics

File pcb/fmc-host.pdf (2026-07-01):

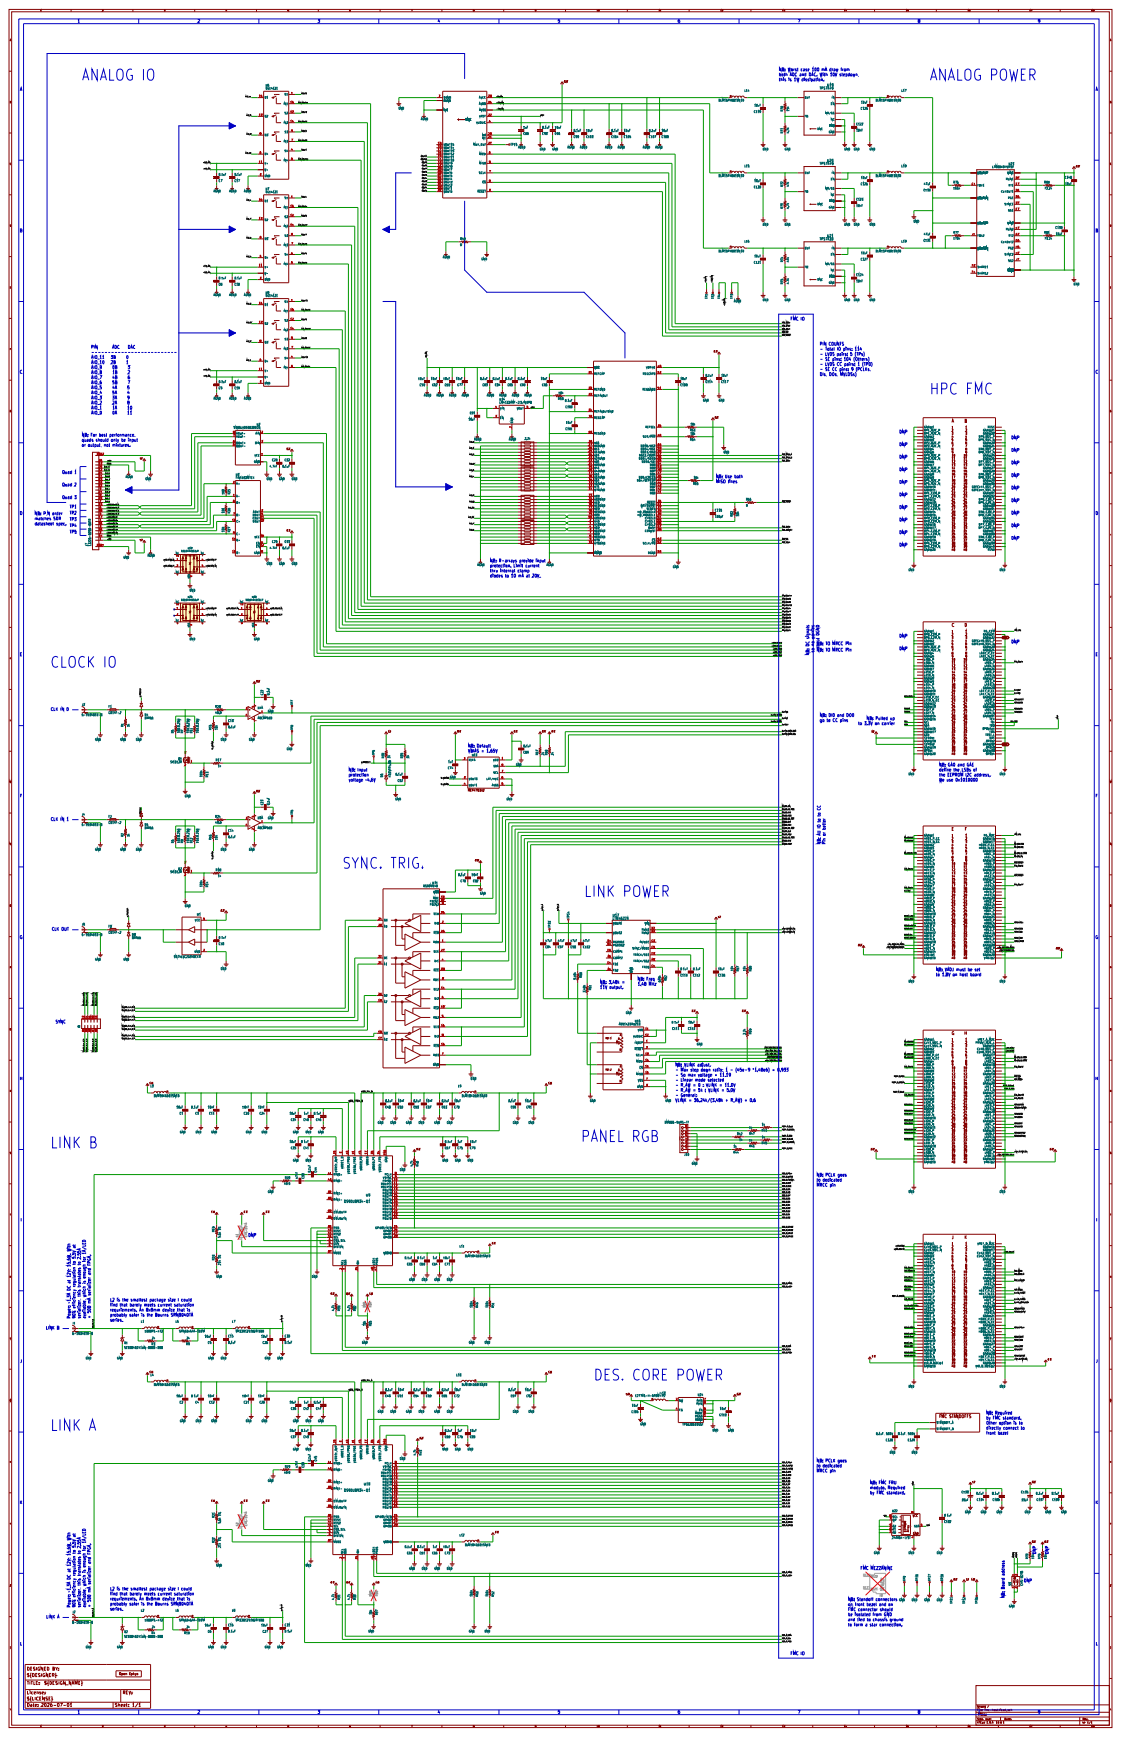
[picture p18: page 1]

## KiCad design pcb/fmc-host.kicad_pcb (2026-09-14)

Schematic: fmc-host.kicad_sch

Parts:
C1, C2, C5, C6, C26, C27, C34, C35, C36, C37, C70, C71, C72, C73, C79, C80, C81, C91, C92, C106, C118, C139, C140: 10uF; 1206; MPN GRM31CR71E106KA12L
C3, C4, C7, C8, C9, C10, C13, C14, C15, C16, C17, C18, C19, C22, C23, C30, C31, C32, C33, C41, C43, C44, C45, C46, C47, C48, C49, C52, C53, C54, C55, C56, C60, C61, C63, C65, C67, C68, C78, C83, C84, C85, C86, C87, C89, C90, C93, C99, C100, C104, C107, C110, C111, C112, C114, C132, C134, C135, C137, C138, C141, C142: 0.1uF; 0402; Voltage 25V; MPN GRM155R71E104KE14D
C11, C12, C20, C21, C24, C25, C50, C51, C57, C58, C82, C122, C123, C124: 10nF; 0402; MPN GCM155R71E103KA37D
C28, C29: 4.7nF; 0402; MPN CC0402KRX7R8BB472
C38, C39: 47nF; 0402; MPN GRM155R71E473KA88D
C40, C42, C64, C66, C74, C75, C76, C88: 1uF; 0805; MPN GCM21BR71E105KA56L
C59, C62, C69, C77, C95, C96, C101, C103, C105, C108, C109, C113, C116, C117, C119, C120, C121, C125, C126, C127: 10uF; 0805; MPN GRM21BR61E106KA73L
C94, C97, C98, C102, C130, C131: 47uF; 1210; MPN TMK325ABJ476MM-T
C115: 100pF; 0402; MPN CC0402JRNPO9BN101
C128, C129: 0.1uF, 500V; 1210; MPN C1210C104KCRACTU
C133, C136: 33uF; 1411-VISHAY-B; MPN TL8B0336M020C
D1, D2: SESD0402X1UN-0030-088; 0402P-DFN; MPN SESD0402X1UN-0030-088
D3, D4, D5: BAR66; SOT23; MPN BAR66E6327HTSA1
D6: KDZVTR4.3B; SOD123; MPN KDZVTR4.3B
F1, F2, F3: C014F-2; 1812; MPN MINISMDC014F-2
J1, J2, J3, J4, J5: 6-1634010-0; MMCX-THRU; MPN 262105
J6: FTSH-105-01-F-D-RA-K; MPN FTSH-105-01-F-D-RA-K
J7: 12226-8250-00FR; 12226-82X0-00XX; MPN 12226-8250-00FR
J8: FMC_SINGLE_WIDTH_MODULE; not fitted
J9: ASP-134488-01; FMC_HPC_MALE; MPN ASP-134488-01
J10: BM08B-SURS-TF; MPN BM08B-SURS-TF
L1, L2: 1008PS-472; 1008PS; MPN 1008PS-472KLC
L3, L4, L9, L10, L11, L12: BLM18KG601SN1D; 0603; MPN BLM18KG601SN1D
L5, L6: SRN6045TA-101M; SRN6045TA; MPN SRN6045TA-101M
L7, L8: MPZ2012S102AT000; 0805; MPN MPZ2012S102AT000
L13: 1277AS-H-6R8M=P2; 1210; MPN 1277AS-H-6R8M=P2
L14, L15, L16, L17, L18, L19: BLM15PX601SN1D; 0402; MPN BLM15PX601SN1D
Q1, Q2, Q3, Q4: SI1012R; SC75; MPN SI1012CR-T1-GE3
R1, R2, R38, R39: 3k; 0402; MPN ERJ-2RKF3001X
R3, R4, R9, R10, R57, R58: 2k; 0402; MPN ERJ-2RKF2001X
R5, R6, R7, R8, R11, R12: 150,0.25W; 0603; MPN CRGP0603F150R
R13, R14, R49, R50, R51, R52, R76, R83, R84: 165k; 0402; MPN ERJ-2RKF1653X
R15, R16, R35, R37, R59, R63, R64, R65, R67, R68, R78, R79, R82: 10k; 0402; MPN ERJ-2RKF1002X
R17, R18, R41, R42, R44, R45, R46, R47: 1k; 0402; MPN ERJ-2RKF1001X
R19, R21: 5.6k 1%; 0402; MPN ERJ-2RKF5601X
R20, R22: 21k 1%; 0402; MPN ERJ-2RKF2102X
R23, R24, R28, R29: 49.9; 0402; MPN RR0510R-49R9-D
R25, R26, R27: 100; 0402; MPN ERJ-2RKF1000X
R30, R31, R32, R33, R40, R43, R71, R73, R75: 4.7k; 0402; MPN ERJ-2RKF4701X
R34, R36: DNP; 0402; MPN DNP; not fitted
R48, R66: 0; 0402; MPN RC0402JR-070RL
R53, R54, R55, R56: 2.2k; RN2X8-1506; MPN EXB-2HV222JV
R60, R61: 3.48k; 0402; MPN ERJ-2RKF3481X
R62: 649k; 0402; MPN ERJ-2RKF6493X
R69: 2.2k; 0402; MPN ERJ-2RKF2201X
R70: 15k; 0402; MPN ERJ-2RKF1502X
R72, R74: 47k; 0402; MPN ERJ-2RKF4702X
R77: 178k; 0402; MPN ERJ-2RKF1783X
R80, R81: 73.2k; 0402; MPN ERJ-2RKF7322X
R289, R290: 4.7,1W; R_1206_3216Metric; MPN SG73P2BTTD4R7J
S1, S2: CHS-01TA; DIP01-SMD-GULL; MPN CHS-01TA; not fitted
S3: CHS-02TB; MPN CHS-02TB
TP1, TP2, TP4, TP5, TP6, TP7, TP11, TP12, TP13, TP14, TP15, TP16: TPB1,27; B1,27
TP3, TP8, TP9, TP10, TP17, TP18: TPB2,54; B2,54
U1: SN74LVC2G34DCKR; SC70; MPN SN74LVC2G34DCKR
U2: SN65LVDS9638DGN; MSOP-8-PAD-3X3; MPN SN65LVDS9638DGN
U3: FIN1032MTCX; TSSOP-16; MPN FIN1032MTCX
U4, U5: ADCMP600; SOT-23-5; MPN ADCMP600BRJZ-R2
U6, U7, U8: DG1412E; QFN16-4X4MM; MPN DG1412EEN-T1-GE4
U9, U10: DS90UB934-Q1; WQFN48-7X7-PAD; MPN DS90UB934TRGZRQ1
U11: DS91M040; WQFN32-5X5; MPN DS91M040TSQ/NOPB
U12: AD5766BCPZ-RL7; CP_40_7; MPN AD5766BCPZ-RL7
U13: MCP47FEB02A0-E/ST; TSSOP-8; MPN MCP47FEB02A0-E/ST
U14: LM4132AMF-2.5/NOPB; SOT-23-5; MPN LM4132AMF-2.5/NOPB
U15: AD7616BSTZ; ST_80_2; MPN AD7616BSTZ
U16: AD5142BRUZ10; TSSOP-16_4.4X5.0; MPN AD5142BRUZ10
U17: LTM4622A; BGA_5X5_625X625; MPN LTM4622AIY#PBF
U18, U25, U26: D3V3XA4B10LP; Diodes_UDFN-10_1.0x2.5mm_P0.5mm; MPN D3V3XA4B10LP-7
U19, U20: TPS7A49; PVSON-N8+4-3X3; MPN TPS7A4901DRBR
U21: TPS7A30; PVSON-N8+4-3X3; MPN TPS7A3001DRBT
U22: 24AA64-I/ST; TSSOP8; MPN 24AA64-I/ST
U23: LTM8049IY#PBF; LTM8049; MPN LTM8049IY#PBF
U24: TPS62061DSGT; WSON8-2X2; MPN TPS62061DSGT
U27: TLV9062IDSGR; WSON-8-1EP_2x2mm_P0.5mm_EP0.9x1.6mm; MPN TLV9062IDSGR
U28: SN74LVC2G14DBV; SOT-23-6; MPN SN74LVC2G14DBVR
X2: OE-LOGO_7X5; OE-LOGO-7X5

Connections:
+1V8: C86.2, C87.2, C91.2, C92.2, C106.2, L3.2, L4.2, L9.1, L10.1, L13.1, R19.1, R21.1, R34.1, R36.1, TP16.TP (TP_TP), U9.17 (VDD18), U10.17 (VDD18), U24.4 (FB)
+3V3: C10.2, C22.1, C23.1, C28.1, C29.1, C32.1, C33.1, C74.2, C78.2, C82.2, C89.2, C93.2, C96.2, C111.2, C113.2, C114.2, C117.2, C118.2, C136.A (+), C137.2, C138.2, C139.1, C140.1, C141.1, C142.1, J9.E39 (VADJ@1), J9.F40 (VADJ@2), J9.G39 (VADJ@1), J9.H40 (VADJ@2), J9.J39 (VIO_B_M2C@1), J9.K40 (VIO_B_M2C@2), L11.1, L12.1, R30.2, R31.2, R32.2, R33.2, R40.2, R43.2, R57.2, R58.2, R64.1, R65.1, R69.1, R78.2, R79.2, S1.2, S2.2, TP11.TP (TP_TP), U1.5 (VCC), U2.1 (VCC), U3.4 (EN), U3.16 (VCC), U4.5 (V+), U5.5 (V+), U9.4 (OSS_SEL), U9.5 (OEN), U10.4 (OSS_SEL), U10.5 (OEN), U11.11 (VDD), U11.12 (VDD), U11.29 (VDD), U11.30 (VDD), U12.4 (VLOGIC), U13.1 (VDD), U13.2 (REFA), U15.49 (VDRIVE), U16.1 (INDEP), U16.11 (VDD), U16.12 (VLOGIC), U23.A5 (VIN1), U23.A6 (VIN1), U23.A7 (VIN1), U23.B7 (RUN1), U23.K7 (RUN2), U23.L5 (VIN2), U23.L6 (VIN2), U23.L7 (VIN2), U24.5 (EN), U24.6 (MODE), U24.7 (AVIN), U24.8 (PVIN), U27.8 (V+), U28.5 (V_{CC})
+12V: C116.2, C133.A (+), C134.2, C135.2, J7.1, J7.26, J9.C35 (12P0V1), J9.C37 (12P0V2), R38.2, R39.2, TP12.TP (TP_TP), U17.A2 (VIN), U17.B3 (VIN), U17.D3 (VIN), U17.E2 (VIN)
/+5V_AN: C59.2, C62.2, C69.2, C77.2, C81.1, C83.2, C84.2, C85.2, C90.2, C107.2, C108.2, L14.1, TP1.TP (TP_TP), U12.28 (AVCC), U14.3 (EN), U14.4 (VIN), U15.6 (VCC), U15.15 (VCC), U15.30 (VCC), U15.71 (VCC)
/+13V_AN: C7.2, C8.2, C9.2, C104.2, C105.2, L15.1, TP2.TP (TP_TP), U6.11 (V+), U7.11 (V+), U8.11 (V+), U12.26 (AVDD)
/-13V_AN: C17.2, C18.2, C19.2, C99.2, C103.2, L16.1, TP4.TP (TP_TP), U6.2 (V-), U6.PAD (V-), U7.2 (V-), U7.PAD (V-), U8.2 (V-), U8.PAD (V-), U12.6 (AVSS), U12.PAD (AVSS)
/ADC_BUSY: J9.J12 (HA11_P), U15.67 (BUSY)
/ADC_CONVST: J9.K13 (HA10_P), U15.68 (CONVST)
/ADC_MISO_A: J9.K11 (HA06_N), U15.57 (DB12/SDOA)
/ADC_MISO_B: J9.J10 (HA07_N), U15.56 (DB11/SDOB)
/ADC_MOSI: J9.K10 (HA06_P), U15.55 (DB10/SDI)
/ADC_SCLK: J9.J13 (HA11_N), U15.62 (SCLK/~RD)
/ADDR0: J9.C27 (LA27_N), R78.1, S3.4
/ADDR1: J9.C26 (LA27_P), R79.1, S3.3
/AIN_AOUT0: J9.F11 (HA08_N), U8.15 (IN1)
/AIN_AOUT1: J9.D11 (LA05_P), U8.6 (IN4)
/AIN_AOUT2: J9.E12 (HA13_P), U8.7 (IN3)
/AIN_AOUT3: J9.H10 (LA04_P), U8.14 (IN2)
/AIN_AOUT4: J9.E18 (HA20_P), U7.15 (IN1)
/AIN_AOUT5: J9.J9 (HA07_P), U7.6 (IN4)
/AIN_AOUT6: J9.G10 (LA03_N), U7.7 (IN3)
/AIN_AOUT7: J9.F17 (HA15_N), U7.14 (IN2)
/AIN_AOUT8: J9.H20 (LA15_N), U6.7 (IN3)
/AIN_AOUT9: J9.J19 (HA18_N), U6.14 (IN2)
/AIN_AOUT10: J9.G19 (LA16_N), U6.6 (IN4)
/AIN_AOUT11: J9.H19 (LA15_P), U6.15 (IN1)
/AIO_0: J7.7, R53.C1, U8.16 (D1)
/AIO_1: J7.20, R53.C3, U8.5 (D4)
/AIO_2: J7.8, R53.C5, U8.8 (D3)
/AIO_3: J7.21, R53.C8, U8.13 (D2)
/AIO_4: J7.9, R54.C4, U7.16 (D1)
/AIO_5: J7.22, R54.C2, U7.5 (D4)
/AIO_6: J7.10, R56.C5, U7.8 (D3)
/AIO_7: J7.23, R56.C7, U7.13 (D2)
/AIO_8: J7.11, R55.C6, U6.8 (D3)
/AIO_9: J7.24, R55.C8, U6.13 (D2)
/AIO_10: J7.12, R55.C4, U6.5 (D4)
/AIO_11: J7.25, R55.C1, U6.16 (D1)
/AOUT0: U6.1 (S1), U12.32 (VOUT0)
/AOUT1: U6.4 (S4), U12.33 (VOUT1)
/AOUT2: U6.9 (S3), U12.34 (VOUT2)
/AOUT3: U6.12 (S2), U12.35 (VOUT3)
/AOUT4: U7.1 (S1), U12.36 (VOUT4)
/AOUT5: U7.4 (S4), U12.37 (VOUT5)
/AOUT6: U7.12 (S2), U12.38 (VOUT6)
/AOUT7: U7.9 (S3), U12.39 (VOUT7)
/AOUT8: U8.9 (S3), U12.12 (VOUT8)
/AOUT9: U8.12 (S2), U12.13 (VOUT9)
/AOUT10: U8.4 (S4), U12.14 (VOUT10)
/AOUT11: U8.1 (S1), U12.15 (VOUT11)
/CLKIN0: J9.D21 (LA17_N_CC), TP7.TP (TP_TP), U4.1 (OUT)
/CLKIN1: J9.E19 (HA20_N), TP6.TP (TP_TP), U5.1 (OUT)
/CLKIN_TERM0: J9.K19 (HA21_P), R17.1
/CLKIN_TERM1: J9.K17 (HA17_N_CC), R18.1
/CLKIN_VBIAS_SCL: J9.J21 (HA22_P), R58.1, U13.7 (SCL)
/CLKIN_VBIAS_SDA: J9.K20 (HA21_N), R57.1, U13.8 (SDA)
/CLKOUT: J9.D20 (LA17_P_CC), U1.1 (IN3), U1.3 (IN2)
/DAC_MISO: J9.K16 (HA17_P_CC), U12.9 (MISO)
/DAC_MOSI: J9.H14 (LA07_N), U12.5 (MOSI)
/DAC_SCLK: J9.J15 (HA14_P), U12.7 (SCLK)
/DES_A_D0: J9.F34 (HB16_P), U10.24 (ROUT0)
/DES_A_D1: J9.K35 (HB14_N), U10.23 (ROUT1)
/DES_A_D2: J9.J34 (HB15_N), U10.22 (ROUT2)
/DES_A_D3: J9.K34 (HB14_P), U10.21 (ROUT3)
/DES_A_D4: J9.E33 (HB19_P), U10.19 (ROUT4)
/DES_A_D5: J9.J33 (HB15_P), U10.18 (ROUT5)
/DES_A_D6: J9.F32 (HB12_N), U10.16 (ROUT6)
/DES_A_D7: J9.E31 (HB13_N), U10.15 (ROUT7)
/DES_A_D8: J9.K32 (HB10_N), U10.14 (ROUT8)
/DES_A_D9: J9.F31 (HB12_P), U10.13 (ROUT9)
/DES_A_D10: J9.J31 (HB11_N), U10.12 (ROUT10)
/DES_A_D11: J9.K31 (HB10_P), U10.11 (ROUT11)
/DES_A_GPIO0: J9.J37 (HB18_N), U10.28 (GPIO0)
/DES_A_GPIO1: J9.K37 (HB17_P_CC), U10.27 (GPIO1)
/DES_A_GPIO2: J9.J36 (HB18_P), U10.26 (GPIO2)
/DES_A_GPIO3: J9.E34 (HB19_N), R43.1, U10.25 (GPIO3/INTB)
/DES_A_HSYNC: J9.E30 (HB13_P), U10.10 (HSYNC)
/DES_A_LOCK: J9.E27 (HB09_P), R50.2, U10.48 (LOCK)
/DES_A_PASS: J9.J28 (HB07_N), R52.2, U10.47 (PASS)
/DES_A_PCLK: J9.K28 (HB06_P_CC), U10.8 (PCLK)
/DES_A_PDB: J9.F35 (HB16_N), U10.30 (PDB)
/DES_A_SCL: J9.F29 (HB08_N), R31.1, U10.2 (SCL)
/DES_A_SDA\: J9.E28 (HB09_N), R33.1, U10.1 (SDA)
/DES_A_VSYNC: J9.J30 (HB11_P), U10.9 (VSYNC)
/DES_B_D0: J9.H29 (LA24_N), U9.24 (ROUT0)
/DES_B_D1: J9.H28 (LA24_P), U9.23 (ROUT1)
/DES_B_D2: J9.G28 (LA25_N), U9.22 (ROUT2)
/DES_B_D3: J9.G27 (LA25_P), U9.21 (ROUT3)
/DES_B_D4: J9.D27 (LA26_N), U9.19 (ROUT4)
/DES_B_D5: J9.D26 (LA26_P), U9.18 (ROUT5)
/DES_B_D6: J9.H26 (LA21_N), U9.16 (ROUT6)
/DES_B_D7: J9.G25 (LA22_N), U9.15 (ROUT7)
/DES_B_D8: J9.H25 (LA21_P), U9.14 (ROUT8)
/DES_B_D9: J9.D24 (LA23_N), U9.13 (ROUT9)
/DES_B_D10: J9.G24 (LA22_P), U9.12 (ROUT10)
/DES_B_D11: J9.D23 (LA23_P), U9.11 (ROUT11)
/DES_B_GPIO0: J9.H32 (LA28_N), U9.28 (GPIO0)
/DES_B_GPIO1: J9.G31 (LA29_N), U9.27 (GPIO1)
/DES_B_GPIO2: J9.H31 (LA28_P), U9.26 (GPIO2)
/DES_B_GPIO3: J9.G30 (LA29_P), R40.1, U9.25 (GPIO3/INTB)
/DES_B_HSYNC\: J9.H23 (LA19_N), U9.10 (HSYNC)
/DES_B_LOCK: J9.J22 (HA22_N), R49.2, U9.48 (LOCK)
/DES_B_PASS: J9.K22 (HA23_P), R51.2, U9.47 (PASS)
/DES_B_PCLK: J9.C22 (LA18_P_CC), U9.8 (PCLK)
/DES_B_PDB: J9.G33 (LA31_P), U9.30 (PDB)
/DES_B_SCL: J9.G22 (LA20_N), R30.1, U9.2 (SCL)
/DES_B_SDA: J9.H22 (LA19_P), R32.1, U9.1 (SDA)
/DES_B_VSYNC: J9.K23 (HA23_N), U9.9 (VSYNC)
/DI_VBIAS0: R15.1, U13.3 (VOUT0)
/DI_VBIAS1: R16.1, U13.4 (VOUT1)
/DOUTP_F_A: C45.2, D2.C, J2.SIG (1), L2.2, R4.2
/DOUTP_F_B: C44.2, D1.C, J1.SIG (1), L1.2, R3.2
/FMC_PG: J9.D1 (PG_C2M), J9.F1 (PG_M2C)
/LINK_A_PWR_EN: J9.H37 (LA32_P), R68.1, U17.B2 (RUN2), U28.1 (1A)
/LINK_B_PWR_EN: J9.K38 (HB17_N_CC), R67.1, U17.D2 (RUN1), U28.3 (2A)
/LINK_PWR_ADJ_MISO: J9.F37 (HB20_P), R69.2, U16.15 (MISO)
/LINK_PWR_ADJ_MOSI: J9.E36 (HB21_P), U16.14 (MOSI)
/LINK_PWR_ADJ_SCLK: J9.H38 (LA32_N), U16.13 (SCLK)
/LVDS_DIN0: J9.J2 (CLK3_M2C_P), U3.3 (AOUT)
/LVDS_DIN0_N: J7.4, R25.1, U3.1 (A-), U18.1, U18.10 (NC)
/LVDS_DIN0_P: J7.17, R25.2, U3.2 (A+), U18.2, U18.9 (NC)
/LVDS_DIN1: J9.H5 (CLK0_M2C_N), U3.5 (BOUT)
/LVDS_DIN1_N: J7.16, R26.1, U3.7 (B-), U18.5, U18.6 (NC)
/LVDS_DIN1_P: J7.3, R26.2, U3.6 (B+), U18.4, U18.7 (NC)
/LVDS_DIN2: J9.H4 (CLK0_M2C_P), U3.11 (COUT)
/LVDS_DIN2_N: J7.2, R27.1, U3.9 (C-), U25.5
/LVDS_DIN2_P: J7.15, R27.2, U3.10 (C+), U25.4
/LVDS_DOUT0: J9.J3 (CLK3_M2C_N), U2.2 (AIN)
/LVDS_DOUT0_N: J7.19, U2.7 (AOUT-), U26.4, U26.7 (NC)
/LVDS_DOUT0_P: J7.6, U2.8 (AOUT+), U26.5, U26.6 (NC)
/LVDS_DOUT1: J9.K4 (CLK2_M2C_P), U2.3 (BIN)
/LVDS_DOUT1_N: J7.18, U2.5 (BOUT-), U26.1, U26.10 (NC)
/LVDS_DOUT1_P: J7.5, U2.6 (BOUT+), U26.2, U26.9 (NC)
/MLVDS_CLK_0_N: J6.10, U11.24 (B0)
/MLVDS_CLK_0_P: J6.09 (9), U11.23 (A0)
/MLVDS_CLK_1_N: J6.08 (8), U11.22 (B1)
/MLVDS_CLK_1_P: J6.07 (7), U11.21 (A1)
/MLVDS_CLK_2_N: J6.04 (4), U11.20 (B2)
/MLVDS_CLK_2_P: J6.03 (3), U11.19 (A2)
/MLVDS_CLK_3_N: J6.02 (2), U11.18 (B3)
/MLVDS_CLK_3_P: J6.01 (1), U11.17 (A3)
/MLVDS_DE_~RE0: J9.F7 (HA04_P), U11.25 (DE0), U11.26 (~RE0)
/MLVDS_DE_~RE1: J9.E7 (HA05_N), U11.27 (DE1), U11.28 (~RE1)
/MLVDS_DE_~RE2: J9.H7 (LA02_P), U11.13 (~RE2), U11.14 (DE2)
/MLVDS_DE_~RE3: J9.H8 (LA02_N), U11.15 (~RE3), U11.16 (DE3)
/MLVDS_DI0: J9.F5 (HA00_N_CC), U11.2 (DI0)
/MLVDS_DI1: J9.E2 (HA01_P_CC), U11.4 (DI1)
/MLVDS_DI2: J9.E3 (HA01_N_CC), U11.6 (DI2)
/MLVDS_DI3: J9.G3 (CLK1_M2C_N), U11.8 (DI3)
/MLVDS_EN: J9.F8 (HA04_N), U11.10 (MDE)
/MLVDS_RO0: J9.F4 (HA00_P_CC), U11.1 (RO0)
/MLVDS_RO1: J9.G6 (LA00_P_CC), U11.3 (RO1)
/MLVDS_RO2: J9.G7 (LA00_N_CC), U11.5 (RO2)
/MLVDS_RO3: J9.G2 (CLK1_M2C_P), U11.7 (RO3)
/PORT_A_BLUE: J9.G18 (LA16_P), R41.2
/PORT_A_GREEN: J9.J18 (HA18_P), R47.2
/PORT_A_RED: J9.H17 (LA11_N), R42.1
/PORT_B_BLUE: J9.H16 (LA11_P), R45.2
/PORT_B_GREEN: J9.G15 (LA12_P), R46.2
/PORT_B_RED: J9.G13 (LA08_N), R44.2
/SCL: J9.C30 (SCL), U22.6 (SCL)
/SDA: J9.C31 (SDA), U22.5 (SDA)
/TDI-TDO: J9.D30 (TDI), J9.D31 (TDO)
/VAUX: C132.2, J9.D32 (3P3VAUX), U22.8 (VCC)
/VDD_FPDX_A: C2.2, C4.2, C12.2, C21.2, C25.2, L4.1, U10.31 (VDD18_FPD1), U10.40 (VDD18_FPD0)
/VDD_FPDX_B: C1.2, C3.2, C11.2, C20.2, C24.2, L3.1, U9.31 (VDD18_FPD1), U9.40 (VDD18_FPD0)
/VDD_PX_A: C49.2, C51.2, C54.2, C58.2, C65.2, C72.2, L10.2, U10.36 (VDD18_P1), U10.45 (VDD18_P0)
/VDD_PX_B: C48.2, C50.2, C53.2, C57.2, C63.2, C70.2, L9.2, U9.36 (VDD18_P1), U9.45 (VDD18_P0)
/VLINK_A: C27.2, C31.1, C94.2, C97.2, L8.1, Q3.3 (D), TP13.TP (TP_TP), U17.A1 (VOUT2), U17.B1 (VOUT2)
/VLINK_B: C26.2, C30.1, C98.2, C102.2, L7.1, Q4.3 (D), TP14.TP (TP_TP), U17.D1 (VOUT1), U17.E1 (VOUT1)
/VREF: C88.2, R59.2, U12.22 (VREF), U14.5 (VOUT)
/V_PROTECT: C52.2, D3.2 (C), D4.2 (C), D5.2 (C), D6.C, R38.1, R39.1, TP5.TP (TP_TP)
/~ADC_CS: J9.H13 (LA07_P), U15.63 (~CS)
/~ADC_RESET: J9.F10 (HA08_P), R66.2
/~DAC_CS: J9.J16 (HA14_N), U12.8 (~CS)
/~DAC_RESET: J9.F14 (HA12_N), U12.3 (~RESET)
/~LINK_PWR_ADJ_CS: J9.F38 (HB20_N), U16.16 (~CS)
/~LINK_PWR_ADJ_RESET: J9.E37 (HB21_N), U16.2 (~RESET)
AGND: C7.1, C8.1, C9.1, C17.1, C18.1, C19.1, C59.1, C62.1, C69.1, C77.1, C81.2, C83.1, C84.1, C85.1, C88.1, C90.1, C95.1, C99.1, C100.1, C101.1, C103.1, C104.1, C105.1, C107.1, C108.1, J7.13, J7.14, R48.1, R53.C2, R53.C4, R53.C6, R53.C7, R54.C1, R54.C3, R54.C5, R54.C6, R54.C7, R54.C8, R55.C2, R55.C3, R55.C5, R55.C7, R56.C1, R56.C2, R56.C3, R56.C4, R56.C6, R56.C8, TP3.TP (TP_TP), U6.3 (GND), U7.3 (GND), U8.3 (GND), U12.10 (AGND), U12.20 (NIC), U12.23 (N0), U12.24 (N1), U12.25 (NIC), U12.29 (AGND), U12.31 (NIC), U14.2 (GND), U15.5 (AGND), U15.16 (AGND), U15.29 (AGND), U15.32 (REFGND), U15.34 (REFINOUTGND), U15.69 (REGGND), U15.72 (AGND)
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

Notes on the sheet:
DNP
LINK POWER
LINK A
NB: Default VBIAS = 1.65V
L2 is the smallest package size I could find that barely meets current saturation requriements. An 8x8mm device that is probably safer is the Bourns SRN8040TA series.
FMC IO
NB: VLINK adjust. - Max step down ratio: 1 - (45e-9 *1.48e6) = 0.933 - So max voltage = 11.19 - Linear mode selected - R_AW = 0 : VLINK = 11.0V - R_AW = 5k : VLINK = 5.0V - General: VLINK = 36.24k/(3.48k + R_AW) + 0.6
TP2
NB: GA0 and GA1 define the LSBs of the EEPROM I2C address. We use 0x1010000
FMC MEZZANINE
ANALOG IO
NB: Pulled up to 3.3V on carrier
TP1
CLK IN 1
SYNC. TRIG.
CLK OUT
SYNC
TP5
NB: Freq = 1.48 MHz
Quad 2
PIN ADC DAC -------------------------- AIO_11 3B 0 AIO_10 2B 1 AIO_9 0B 3 AIO_8 1B 2 AIO_7 4B 6 AIO_6 5B 7 AIO_5 4A 5 AIO_4 5A 4 AIO_3 3A 9 AIO_2 2A 8 AIO_1 1A 10 AIO_0 0A 11
NB: TO MRCC Pin
Quad 1
PIN COUNTS - Total IO pins: 114 - LVDS pairs: 5 (TPs) - SE pins: 104 (Others) - LVDS CC pairs: 1 (TP0) - SE CC pins: 9 (PCLKs, DIs, DOs, MVLDSs)
NB: PCLK goes to dedicated MRCC pin
NB: DI0 and DO0 go to CC pins
TP3
Quad 3
NB: P,N order matches SDR datasheet spec.
PANEL RGB
NB: Standoff connectors on front bezel and on FMC connector should be isolated from GND and tied to chassis ground to form a star connection.
CLK IN 0
HPC FMC
CLOCK IO
NB: 3.48k = 11V output.
NB: Worst case 100 mA draw from both ADC and DAC. With 10V stepdown, this is 1W dissipation.
NB: VADJ must be set to 1.8V on host board~{}
NB: R-arrays provide input protection. Limit current thru internal clamp diodes to 10 mA at 20V.
NB: DC signals so no worries about DGND
NB: Input protection voltage ~4.6V

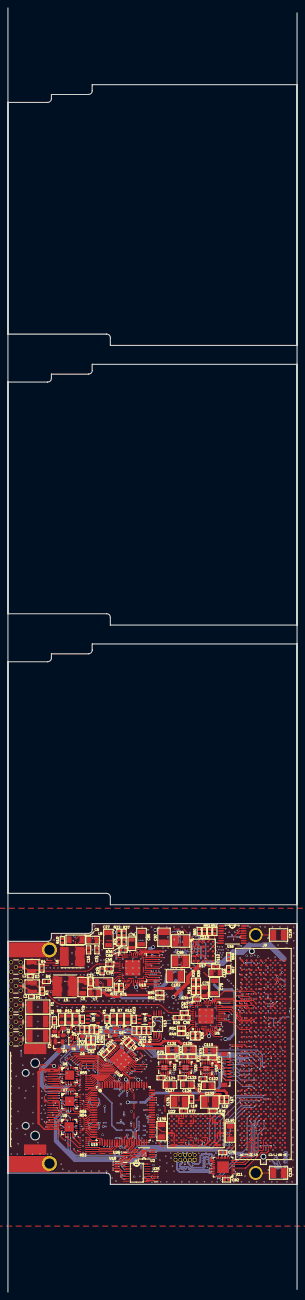
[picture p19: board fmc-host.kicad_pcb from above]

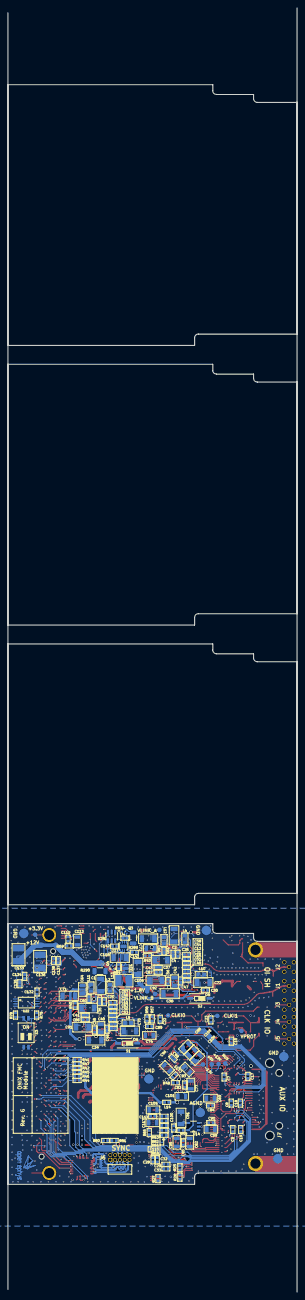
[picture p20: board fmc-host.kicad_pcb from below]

Board: 6 copper layers, 76.5 x 339.8 mm, 320 parts (163 on the bottom side), 300 nets.

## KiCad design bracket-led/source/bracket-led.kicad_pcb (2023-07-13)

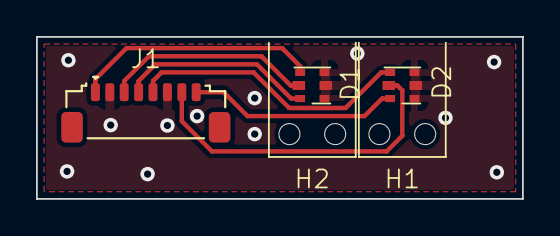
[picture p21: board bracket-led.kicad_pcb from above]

Board: 2 copper layers, 27.0 x 9.0 mm, 5 parts (0 on the bottom side), 7 nets.

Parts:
D1, D2: LED_RGB; EVERLIGHT_6-SMD-1.6x1.6
H1, H2: SLP3-150-100-R; BIVAR_SLP3-150-100-R
J1: SM08B-SURS-TF(LF)(SN); JST_SM08B-SURS-TF(LF)(SN)

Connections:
B_{A}: D2.1 (BA), J1.8
B_{B}: D1.1 (BA), J1.4
GND: D1.2 (BK), D1.4 (RK), D1.6 (GK), D2.2 (BK), D2.4 (RK), D2.6 (GK), J1.2, J1.6
G_{A}: D2.5 (GA), J1.5
G_{B}: D1.5 (GA), J1.1
R_{A}: D2.3 (RA), J1.7
R_{B}: D1.3 (RA), J1.3

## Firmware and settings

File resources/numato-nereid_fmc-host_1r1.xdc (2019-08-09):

####################################################################################################################
#                                               CLOCK 100MHz                                                       #
####################################################################################################################
set_property -dict { PACKAGE_PIN "F22"    IOSTANDARD LVCMOS33   SLEW FAST} [get_ports { CLK1 }]     ;                           # IO_L12P_T1_MRCC_14            Sch = CLK1

set_property -dict { PACKAGE_PIN "D23"    IOSTANDARD LVCMOS33   SLEW FAST} [get_ports { CLK_DIR }]  ;                           # IO_L11P_T1_SRCC_14            Sch = CLK_DIR

####################################################################################################################
#                                              150MHz LVDS Oscillator                                              #
####################################################################################################################
set_property -dict { PACKAGE_PIN "G24"    IOSTANDARD TMDS_33   SLEW FAST} [get_ports { CLK2_P }]     ;                          # IO_L14P_T2_SRCC_14            Sch = CLK2_P
set_property -dict { PACKAGE_PIN "F24"    IOSTANDARD TMDS_33   SLEW FAST} [get_ports { CLK2_N }]     ;                          # IO_L14N_T2_SRCC_14            Sch = CLK2_N

####################################################################################################################
#                                       RESET - SW2 & FAN PWM                                                      #
####################################################################################################################
set_property -dict { PACKAGE_PIN "C26"    IOSTANDARD LVCMOS33   SLEW FAST   PULLDOWN True} [get_ports { RESET }]    ;           # IO_L5N_T0_D07_14              Sch = RESET
set_property -dict { PACKAGE_PIN "J25"    IOSTANDARD LVCMOS33   SLEW FAST   PULLDOWN True} [get_ports { FAN_PWM }]  ;           # IO_L22N_T3_A04_D20_14         Sch = FAN_PWM

####################################################################################################################
#                                               ADC                                                                #
####################################################################################################################
set_property -dict { PACKAGE_PIN "B16"    IOSTANDARD LVCMOS33   SLEW FAST} [get_ports { ADC_A_N[0] }]   ;                       # IO_L1N_T0_AD0N_15             Sch = ADC_A0_N
set_property -dict { PACKAGE_PIN "C16"    IOSTANDARD LVCMOS33   SLEW FAST} [get_ports { ADC_A_P[0] }]   ;                       # IO_L1P_T0_AD0P_15             Sch = ADC_A0_P
set_property -dict { PACKAGE_PIN "A19"    IOSTANDARD LVCMOS33   SLEW FAST} [get_ports { ADC_A_N[1] }]   ;                       # IO_L2N_T0_AD8N_15             Sch = ADC_A1_N
set_property -dict { PACKAGE_PIN "A18"    IOSTANDARD LVCMOS33   SLEW FAST} [get_ports { ADC_A_P[1] }]   ;                       # IO_L2P_T0_AD8P_15             Sch = ADC_A1_P
set_property -dict { PACKAGE_PIN "A17"    IOSTANDARD LVCMOS33   SLEW FAST} [get_ports { ADC_A_N[2] }]   ;                       # IO_L3N_T0_DQS_AD1N_15         Sch = ADC_A2_N
set_property -dict { PACKAGE_PIN "B17"    IOSTANDARD LVCMOS33   SLEW FAST} [get_ports { ADC_A_P[2] }]   ;                       # IO_L3P_T0_DQS_AD1P_15         Sch = ADC_A2_P
set_property -dict { PACKAGE_PIN "N11"    IOSTANDARD LVCMOS33   SLEW FAST} [get_ports { ADC_VREF_N }]   ;                       # VREFN_0                       Sch = ADC_VREF_N
set_property -dict { PACKAGE_PIN "P12"    IOSTANDARD LVCMOS33   SLEW FAST} [get_ports { ADC_VREF_P }]   ;                       # VREFP_0                       Sch = ADC_VREF_P
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

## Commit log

2019-01-20 FMC host module
    - This will deprecate pcie-host
    - Should conform, largely, to VITA-57 standardFeatures
    - 1 deserializer
    - 2 arbitrary logic-level rugged GPIs
    - 1 arbitrary logic-level rugged GPO
    - 8 16-bit analog outputs
    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
    [fmc-host.GBL, fmc-host.GBO, fmc-host.GBS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]
2019-01-20 Updates to fmc-host board
    - Added header for debug (need to connect still)
    - All test points to bottom
    - Silk screen improvements
    [fmc-host.GBL, fmc-host.GBO, fmc-host.GBS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]
2019-01-21 Completed fmc-host board
    - Added debug port that can be plugged into logic analyzer
    - Added pdf of schematic
    - Small silkscreen and routing changes
    [fmc-host.brd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]
2019-01-23 fmc-host board v1.0
    - Ready for fabrication
    - BOM simplification
    - Part renumber
    - Silkscreen update
    [fmc-host.brd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]
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2019-03-04 fmc-host updates after assembly
    - Mostly small layout changes to fix incorrect land patterns, shorts,
    etc.
    - Now we are using external reference for ADC and DAC instead of using
    ADC's
    [fmc-host.GBL, fmc-host.GBO, fmc-host.GBS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]
2019-03-05 Final updates to fmc-host rev 1.1
    - Changes reflect issues found during assembly
    [fmc-host.GBL, fmc-host.GBO, fmc-host.GBS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]
2019-03-05 Changed microstrip on fmc-host to match JLCPCB impednace specs
    - Using JLC7628
    - 50 Ohm trace is 0.3 mm thick (outer layer and first ground plane)
    [fmc-host.brd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]
2019-05-07 Initial commit of 3d printed case for pcie fmc host Designed to slot into the FMC card and then screw into the numato board Many features and dimensions are still missing
    [WaveTherm-OC-PCB-FMC.SLDASM, WaveTherm-OC-PCB-FMC_OC-PCB-FMC.SLDPRT, WaveTherm-OC-PCB-FMC_SAMTEC_ASP-134488-01.sldprt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]
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2019-05-23 Updated fmc pcie case - Fixed screw hole sizes (hopefully) - Less 90s design - Changed to 12mm FMC stack height
    [fmc_host_pcie_case.SLDPRT, fmc_host_pcie_case.STL]
2019-07-28 Initial schematic for fmc-host rev. 1.1
    - High pincount FMC
    - Lots of feature additions and deprecations after learning from rev.
    1.0
    - 2x deserializers instead of 1
    - Remove 20 Ohm series impedance matching resistors from deserializer
    parallel connection because they are not needed
    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
    [fmc-host.brd, fmc-host.sch]
2019-07-30 Initial component placement for fmc-host rev. 1.1
    - 6 layer board with 2 high speed layers
    - Initial routing
    - Added a TODO file to the enclosure folder
    [fmc-host.brd, fmc-host.sch]
2019-08-02 fmc-host rev 1.1 routing progress
    - Labelled all FMC pin connections by IO type and clock capability
    - Almost completely routed analog section (ADC, DAC, and muxing)
    - Starting to bring back digital IO to dummy vias on FMC for arrangement
    [fmc-host.brd, fmc-host.sch]
2019-08-09 Initial FMC pinout largely decided
    - XDC file contains the pinout
    - Need to test sythesis before fully committing and finishing board
    routing
    [fmc-host.brd, fmc-host.sch]
2019-08-12 fmc-host rev. 1.1
    - Completed revision 1.1 of the FMC host module
    - Needs final synthesis testing before fab
    [fmc-host.GBL, fmc-host.GBO, fmc-host.GBS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]
2019-08-15 Small fixes to silk layer on fmc-host rev 1.1
    - Should be ready for fabrication
    - Added some gerber art to gerber folder
    [fmc-host.brd, fmc-host.sch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]
2019-08-26 Replace SMD MMCX with thru hole on fmc-host
    - Less likely to rip off
    - Also, got rid of redundant ground vias around these connectors
    [fmc-host.brd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]
2019-09-23 FMC host board rev. 1.3
    - Some minor changes after building revision 1.2 and implementing FPGA
    design
    - DES_A_PCLK moved to positive pin
    - Swapped DES_B_D[1] and DES_B_D[2]
    - Minor fixes to packages
    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
    [fmc-host.brd, fmc-host.sch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]
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2019-11-17 Updates to fmc-host board when testing revision 1.3
    - This is starting revision 1.4
    - Replaced SPDT analog switches for analog IO with SPST swiches inline
    with the analog outpus. Inputs are always connected. This allows
    loopback of analog output instead of wasting the analog input
    capabilites when a line is selected to be an output
    [fmc-host.GBL, fmc-host.GBO, fmc-host.GBS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]
2019-12-07 headstage-neuropix rev 1.2
    - Dual neuropixels probe support
    - 2X HTC Vive receivers
    - Many changes made for reliability of manufacturing
    [fmc-host.brd, fmc-host.sch]
2020-01-06 fmc-host board rev. 1.4
    - Several small but significant changes to rev. 1.3
    - DES LOCK and PASS lines have pull down resistors now to deal with the
    fact that they are tri-stated when the DES is in PDN mode
    - PDN pin directly driven by FPGA instead of unnecessary FET
    [fmc-host.brd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]
2020-02-07 fmc-host rev. 1.3
    - This revision of the fmc-host board addresses several issues
    encountered during testing of revision 1.2
    - The deserializers have been upgrated to DS90UB934-Q1s. This increases
    the forward channel bandwidth to 14 x 100 MHz and reduces back channel
    latency.
    - The SPDT analog switches on rev. 1.2 have been replaced with SDST
    switches. Analog inputs are perminently connected. So when the anlaog
    outputs are selected, they are measured automatically.
    - The top ground copper now has thermals to make assembly easier
    [fmc-host.GBL, fmc-host.GBO, fmc-host.GBS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]
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2020-02-07 Updated PCIe mounting bracket
    - Increased FMC standoff form 10 to 12mm
    - Added holes for LEDs
    - Fixed markings
    [PCIe_bracket_cnc_thick.SLDPRT, PCIe_bracket_cnc_thick.STL]
2020-02-09 Address Filipe's suggestions prior to fabrication
    - Use grid of cream bloks under QFN center pads instead of one large
    one. Place vias between these blocks where possible
    - Improve silk layer readability
    - Move copper away from dimension in several areas
    - Add SMD mount files
    [fmc-host.GBL, fmc-host.GBO, fmc-host.GBS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]
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2020-02-09 Move silk out from under components where possible in fmc-host
    - Bad practice, esp for passives, due to increase tombstoning risk
    [fmc-host.brd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]
2020-02-12 Fixed LED cutouts for FMC and added little divider
    [PCIe_bracket_cnc_thick.SLDPRT, PCIe_bracket_cnc_thick.STL]
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2020-06-08 Minor updates to fmc-host
    - Fix analog IO select mapping
    - Added html bom
    [fmc-host.GBL, fmc-host.GBO, fmc-host.GBS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]
2020-07-13 Added frozen fmc-host revision 1.4
    - This is the revision that was produced by OEPS for distribution with
    the beta test
    [FMC_10mm_stackheight_spacer.SLDPRT, PCIe bracket slot 1.SLDPRT, PCIe_bracket_cnc_thick.SLDPRT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]
2020-07-13 Started fmc-host revision 1.5
    - Added missing 2.2k pullup resistor to the MISO lines of the dual
    potentiometer, which is an open drain pin
    [fmc-host.brd, fmc-host.sch]
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2020-07-14 Moved the pullup resistor on fmc-host's pot's SDO line away from hole
    - It was too close to the FMC mounting hole and would have been smashed
    by the standoff
    [fmc-host.brd]
2020-10-19 Added frozen fmc-host revision 1.3
    - This is a prototype version that uses the ds90ub914a deserialzer and a
    different muxing scheme from more modern variants on the analog IO
    - It is pretty widely used in the Harnett and Wilson labs
    [fmc-host.GBL, fmc-host.GBO, fmc-host.GBS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]
2020-10-20 Fix several issues while testing fmc-host rev 1.4
    - VADJ on the FMC connector determines the IO voltage of all the "A"
    pins on the FMC connector, and therefore chips driving or receiving from
    these lines must use VADJ for their IO voltage.
    - The IO voltage of all "B" pins on the FMC connector is determined by
    VIO_B_M2C, so I'm feeding VADJ right back into that pin.
    - The 1.8V core voltage for the deserializers is now derived from VADJ
    using a small step down converter
    - Small fixes to strap resistors on MODE and IDX pins of the
    deserializers
    [fmc-host.brd, fmc-host.sch]
2021-06-25 Moved fmc-host into independent repo
    - Did some reorganization as well to make it a bit more like the
    onix-headstage-neuropix1 repo
    [FMC_10mm_stackheight_spacer.SLDPRT, PCIe bracket slot 1.SLDPRT, PCIe_bracket_cnc_thick.SLDPRT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]
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2021-06-26 Replaced revisions folders with tags
    - Tags are rev-1.3 and rev-1.4
    [FMC_10mm_stackheight_spacer.SLDPRT, PCIe bracket slot 1.SLDPRT, PCIe_bracket_cnc_thick.SLDPRT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]
2021-06-28 ONIX FMC Host revision 1.5
    - Lots of minor fixes after extensive testing of 1.4
    - VITA-57 compliance
    - Remove debug points
    - Standalone 1.8V regulator for deserializers
    - Lots of other small fixes
    [fmc-host.GBL, fmc-host.GBO, fmc-host.GBS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]
2021-07-10 Revision 1.6
    - The major change here is that I've swapped the vertical MVLVDS sync
    header for a through-hole right-angle version that is much more
    amenable to daisy chain connections when the card is in a PCIe slot.
    - Deleted some obsolete, hard to maintain files
    - Deleted some obsolete datasheets
    [fmc-host.GBL, fmc-host.GBO, fmc-host.GBS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]
2021-10-25 Redesign of the PCIe bracket
    - Fixed incorrect distances
    - Added inserts for 5mm RGB LEDs for better panel lighting to work wirht
    revision 1.6 (Rev. F)
    - Two versions 2.0 mm and 1.27 mm thick. 2.0 is probably the only
    reasonable one for 3D printing.
    - Shapeways DGPA12GB (Dark Grey PA12 with glass beads) has excellent
    results with 2.0 mm version.
    [FMC_10mm_stackheight_spacer.SLDPRT, PCIe bracket slot 1.SLDPRT, PCIe_bracket_cnc_thick.SLDPRT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]
2021-10-27 Update PCIe bracket after testing
    - Move the FMC supports to the inside and make them solid
    - Make the the portions of the bracket that must interface with the card
    slot thinner to give them a better chance of working (the part should
    really be 0.8mm thick)
    [pcie-bracket-1p27mm.SLDPRT, pcie-bracket-1p27mm.STL, pcie-bracket-2mm.SLDPRT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]
2022-03-09 Revision F ready for fabrication feedback
    - Replaced QFN AD5142 with TSSOP package, which is available
    - Added ground pours to all layers
    - Used thermals on top and bottom to improve solderability
    [fmc-host.GBL, fmc-host.GBO, fmc-host.GBS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]
2022-04-12 Added 3D printable shell for creating ganged MMCX connection
    - Should make it easier for people to get the coax cable ordering
    correct at host
    [mmcx-gang-host.STL, mmcx-gang.SLDPRT, pcie-bracket.SLDASM]
2022-08-22 Remove 2mm thick PCIe bracket
    - Too thick
    - 1.27 mm version is in spec, and should be used
    [pcie-bracket-1p27mm.SLDPRT, pcie-bracket-1p27mm.STL, pcie-bracket-2mm.SLDPRT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]
2023-01-28 Create fmc-host - panel.brd
    Panel is a 2x2 with V-Cut and milling as separation method.
    The distance between individual boards is 5 mm.
    [fmc-host - panel.brd]
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2023-03-30 added clearance for lens
    [pcie bracket glue.SLDPRT, pcie glue assembly.SLDASM]
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2023-05-05 Fixed PCIe Bracket
    - hole spacing fixed
    - exploratory engravings removed
    - logo moved
    - mmcx hole diameter reduced to avoid thin features
    [Flat-pattern_-_pcie-bracket-glue.DXF, bracket-led.SLDASM, bracket-led.step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]
2023-05-05 Fixed Schematic
    - LEDs remapped
    - Mounting pins grounded for mechanical integrity
    - Changed LED symbol (symbol is the same as KiCad generic symbol but
    with renumbered pins)
    - fiber optic included in schematic
    [bom.csv, bracket-led-panel-tight.kicad_pcb, bracket-led.kicad_pcb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]
2023-07-13 fixed pcb led-connector mapping
    be warned that schematic does not match pcb in an effort to get this to filipe for order asap
    [bracket-led-panel-B_Cu.gbr, bracket-led-panel-B_Mask.gbr, bracket-led-panel-B_Paste.gbr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]
2026-03-31 Start KiCAD migration and address rev. F issues
    - Fix clashing reference selection on AD7616
    - Move from AD7617 to AD7616
    - Add TVS diodes to LVDS lines to the breakout board.
    [fmc-host.kicad_pcb, fmc-host.kicad_sch]
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2026-06-30 Fix AD761x nRESET input
    - Replace 0.1uF filter capacitor with 100pF
    - Replace series 10k resistor with 0 ohm jumper
    - Add 10k pulldown so that chip power-on defaults to the reset state
    [fmc-host.kicad_pcb, fmc-host.kicad_sch]
2026-07-01 Updated OEPS PN.
    Added OEPS PN to all components.
    The cross-check between BOM and PNP files failed due to TP (test points) attributes.
    Fixed TP attributes.
    Added .history/ to .gitignore to remove KiCAD history files.
    [fmc-host.kicad_pcb, fmc-host.kicad_sch]
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2026-09-14 Add final production files. Ready for production.
    - Deleted old OEPSPN Field (not being used).
    - Updated BOM generation according to standard.
    - Added revG to schematic and project properties.
    - Added/fixed OEPS Description.
    - Updated PCB with OEPS Description.
    - Regenerated assembly PnP files and merge into one single file.
    - Regenerated BOM and removed duplicated lines.
    - Deleted Edadoc EQ that is now solved.
    New parts added:
    C141, C142 - OEPS010004 GRM155R71E104KE14D
    U27, U28 - OEPS080246 TLV9062IDSGR
    Q3, Q4 - OEPS060024 SI1012CR-T1-GE3
    R83, R84 - OEPS020020 ERJ-2RKF1653X
    R289, R290 - OEPS020260 SG73P2BTTD4R7J
    [fmc-host.csv, fmc-host.kicad_pcb, fmc-host.kicad_sch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]
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

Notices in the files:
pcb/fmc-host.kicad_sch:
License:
